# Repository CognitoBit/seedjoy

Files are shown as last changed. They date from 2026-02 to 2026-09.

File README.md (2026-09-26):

# SeedJoy

Game-controller firmware for the **Seeed Studio XIAO nRF52840**, with a zero-install web
configurator. The board shows up as a standard HID **joystick** over **USB** or **Bluetooth LE**,
with up to **56 buttons** (74HC165 shift registers) and **4 analog axes**.

> **Board:** Seeed Studio XIAO nRF52840, the *non-Sense* board, using the **"Seeed nRF52 Boards"**
> Arduino core (FQBN `Seeeduino:nrf52:xiaonRF52840`). The mbed-based Seeed core and the Sense
> board definition are not supported by this build.

---

## Features

- **56 buttons** from up to 7 daisy-chained 74HC165s on 3 pins (D6/D7/D8), debounced
- **4 analog axes** (A0–A3, 12-bit) with calibration, deadzone, expo curve, smoothing, invert
- **USB HID or BLE HID**, chosen at boot by pin D9
- **Web configurator** (Chrome/Edge): connect over **Web Serial** (USB cable, either mode) or
  **WebBluetooth** (BLE mode), read and write the full config, calibrate axes, and watch live
  button states
- **Persistent config** in on-chip flash (LittleFS, CRC32-checked)
- **Ghost-input protection**: HID input is held off for 60 s after each BLE connection
- **Battery level** reported through the BLE Battery Service (LiPo on the XIAO's BAT pads)
- Force feedback (USB PID) exists as an experimental, **off-by-default** build option, see
  [docs/ffb-plan.md](docs/ffb-plan.md)

---

## Hardware

### Parts

| Part | Qty | Notes |
|---|-----|---|
| Seeed Studio XIAO nRF52840 | 1 | Non-Sense |
| 74HC165 shift register | 1–7 | 8 buttons each |
| 10 kΩ resistor | 1 per button | Pull-up on each 74HC165 input |
| Buttons / switches | up to 56 | Input → GND |
| 10 kΩ linear potentiometer | 0–4 | Optional axes |
| Switch or jumper on D9 | 1 | Only to boot into BLE mode |
| 3.7 V single-cell LiPo | 0–1 | Optional, for wireless use |

**Everything runs at 3.3 V.** Power the 74HC165s, pull-ups and pots from the XIAO's **3V3** pin.
XIAO pins are not 5 V tolerant.

### Pin map

| XIAO pin | Port | Function |
|---|---|---|
| A0–A3 (D0–D3) | P0.02, P0.03, P0.28, P0.29 | Axes 0–3 (X, Y, Z, Rz), **disabled by default** |
| D4, D5, D10 | P0.04, P0.05, P1.15 | Optional direct GPIO buttons, disabled by default |
| **D6** | P1.11 | 74HC165 **data**: QH (pin 9) of the chip nearest the XIAO |
| **D7** | P1.12 | 74HC165 **clock**: CLK (pin 2) of every chip |
| **D8** | P1.13 | 74HC165 **load**: SH/LD (pin 1) of every chip |
| **D9** | P1.14 | **Mode select**: open = USB, GND at boot = BLE |
| RGB LED | P0.26 red, P0.06 blue | Red: booting / error blinks. Blue: USB mounted, or BLE connected |
| BAT+/BAT− pads | n/a | LiPo (underside) |

### Shift-register wiring (74HC165)

```
            far end                                          nearest XIAO
 3V3 → SER[Chip 1]QH → SER[Chip 2]QH → … → SER[Chip 7]QH ──────────► D6
        buttons 1–8    buttons 9–16          buttons 49–56

 D7 → CLK (pin 2) of every chip        D8 → SH/LD (pin 1) of every chip
 3V3 → VCC (16) of every chip           GND → GND (8) and CLK INH (15) of every chip
```

- Chain with **QH (pin 9) → next chip's SER (pin 10)**. Do not use /QH (pin 7); it's inverted.
- The far-end chip's SER goes to **3V3** (so unused chain positions read as released). Buttons
  1–8 are on that chip: input A = button 1, input H = button 8.
- Each input gets a **10 kΩ pull-up to 3V3**, and the switch goes from the input to **GND**.
  Released reads HIGH, pressed reads LOW. The default *Invert Logic = on* reports pressed as 1.
- Fewer than 7 chips is fine. Set **Number of chips** in the configurator to match what's fitted,
  because numbering always starts at the far-end chip.

Full wiring guide with the 74HC165 pinout: [docs/hardware.md](docs/hardware.md).

**Test board:** a ready-to-fab KiCad board that exercises everything (74HC165 + 8 buttons, chain
header, DIP switches, on-board thumbstick, external analog header) is in [pcb/](pcb/). See
[pcb/README.md](pcb/README.md) for the bring-up checklist and [pcb/BOM.md](pcb/BOM.md) for
India-sourced parts.

---

## Build and flash

### 1. Install the board support package

Arduino IDE 2.x or [arduino-cli](https://arduino.github.io/arduino-cli/latest/installation/).
Add this board-manager URL:

```
https://files.seeedstudio.com/arduino/package_seeeduino_boards_index.json
```

Install **Seeed nRF52 Boards** (tested with **1.1.10**). Do *not* install the "mbed-enabled"
package. No extra libraries are needed: TinyUSB, Bluefruit and LittleFS ship with the core.
Don't install a separate "Adafruit TinyUSB" from Library Manager, since it can shadow the
core's copy.

```bash
arduino-cli config add board_manager.additional_urls \
  https://files.seeedstudio.com/arduino/package_seeeduino_boards_index.json
arduino-cli core update-index
arduino-cli core install Seeeduino:nrf52
```

### 2. Compile

```bash
cd firmware/seedjoy
./compile.sh
```

This produces `build/seedjoy.uf2` (drag-and-drop image), `build/seedjoy.ino.zip` (serial DFU
package) and `build/seedjoy.ino.hex`. `compile.sh` uses `arduino-cli` from your `PATH` (or
`~/bin/arduino-cli`).

In the Arduino IDE: open `firmware/seedjoy/seedjoy.ino`, select **Tools → Board → Seeed nRF52
Boards → Seeed XIAO nRF52840** (not "Sense"), then Upload.

### 3. Flash

**Option A: UF2 drag-and-drop (simplest)**

1. Connect the XIAO by USB-C (use a data cable).
2. **Double-tap the RESET button.** A USB drive appears (the UF2 bootloader).
3. Copy `build/seedjoy.uf2` onto that drive. The board reboots into SeedJoy.

**Option B: serial upload**

```bash
./upload.sh              # finds /dev/cu.usbmodem* (macOS) or /dev/ttyACM* (Linux)
PORT=/dev/cu.usbmodem1101 ./upload.sh   # or pick the port yourself
```

Or in the IDE, press Upload. If the port isn't found, double-tap RESET and retry.

### Apple Silicon Macs without Rosetta

Seeed's core 1.1.10 ships **x86_64-only** `arm-none-eabi-gcc` 9-2019q4 and `adafruit-nrfutil`,
and Arduino's `ctags` is x86_64-only too. Without Rosetta, compiling fails with
`bad CPU type in executable`. Either install Rosetta (`softwareupdate --install-rosetta`), or
point the scripts at native tools:

```bash
# 1. Native ARM toolchain (Arm GNU Toolchain, darwin-arm64 tarball, e.g. 13.3.rel1)
#    https://developer.arm.com/downloads/-/arm-gnu-toolchain-downloads
# 2. adafruit-nrfutil from PyPI
python3 -m venv ~/.venvs/nrfutil && ~/.venvs/nrfutil/bin/pip install adafruit-nrfutil
# 3. Arduino's ctags fork, built natively
git clone --depth 1 --branch 5.8-arduino11 https://github.com/arduino/ctags.git
cd ctags && grep -rl __unused__ . | grep -E '\.(c|h)$' | xargs sed -i '' 's/__unused__/CTAGS_UNUSED/g'
./configure && make && cd ..

# then:
ARM_GCC_BIN=/path/to/arm-gnu-toolchain-13.3.rel1-darwin-arm64-arm-none-eabi/bin \
NRFUTIL=~/.venvs/nrfutil/bin/adafruit-nrfutil \
CTAGS_DIR=/path/to/ctags \
./compile.sh

NRFUTIL=~/.venvs/nrfutil/bin/adafruit-nrfutil ./upload.sh   # or just use the UF2 drive
```

This is how the current tree was build-verified: gcc 13.3.rel1, 148 KB flash (18 %), 20.6 KB RAM
(8 %). The "`_close is not implemented`"-style linker warnings from newer newlib are harmless.

---

## First boot and mode selection

D9 is sampled **once at boot** (internal pull-up):

| D9 at reset | Mode | What the host sees |
|---|---|---|
| Nothing connected | **USB** | USB joystick "SeedJoy" + a serial port (VID `0x239A`, PID `0x80F4`) |
| Tied to GND | **BLE** | BLE HID joystick advertising as "SeedJoy" (plus the serial port if USB is plugged in) |

To change mode, change D9 and press RESET. The `mode` field in the saved config is currently
informational only, and D9 always decides.

In USB mode the serial port drops once and reappears about a second after boot. That's expected:
the firmware forces the host to re-enumerate so the joystick interface appears.

Boot log (Serial Monitor, 115200 baud) prints the selected mode, enabled axes and the
shift-register setup.

### Default configuration

| Setting | Default |
|---|---|
| Shift registers | **enabled**, 7 chips, D6/D7/D8, Invert Logic **on** |
| Axes 0–3 | **disabled** (enable only the ones you've wired) |
| Direct GPIO buttons | disabled |
| Device name | `SeedJoy` |

With a full 7-chip chain, a board wired as above works with no configuration at all: SR buttons
appear as HID buttons 1–56. With fewer chips, the fitted chips first show up at the top of the
range (one chip on D6 = buttons 49–56) until you set *Number of chips* in the configurator. Nothing
reads as stuck pressed, as long as the far-end SER is tied to 3V3.

> **Upgrading from an older build?** A config already saved on the board keeps its old values.
> In particular the old default was *Invert Logic = off*, which makes every idle button read as
> pressed with pull-up wiring. Open the configurator, **Read from Device**, tick **Invert Logic**,
> and **Write to Device**.

### Testing it

- **Windows:** `joy.cpl` (Game Controllers), select SeedJoy, then Properties
- **Linux:** `jstest /dev/input/js0`
- **Any OS:** https://hardwaretester.com/gamepad in Chrome

`joy.cpl` and browser gamepad testers display **only the first 32 buttons**. The configurator's
Button Mapping tab shows all 64. Games and SDL/DirectInput apps read the full report.

### BLE mode and the 60-second window

Every time a BLE central connects (your PC *or* the web configurator), the firmware holds off
HID input for **60 seconds** so floating or unconfigured inputs can't spam the host while you
configure. The blue LED lights while connected.

- After pairing with your PC, expect **no input for the first minute** of each connection.
- Send `H` over the serial port to enable HID immediately, or `C` to restart the window.
- Press and hold a button on D9 (to GND) during the window to keep it open. A switch left
  closed since boot is ignored for this, so a permanent BLE jumper won't block HID.

Pair from the OS Bluetooth settings as you would any controller. If pairing gets stuck, remove
"SeedJoy" from the OS device list and reset the board.

---

## Web configurator

### Open it

WebBluetooth and Web Serial need a secure context. `http://localhost` counts as one:

```bash
cd configurator
python3 -m http.server 8000
# open http://localhost:8000 in Chrome or Edge (Firefox/Safari have neither API)
```

### Connect

Pick **🔌 USB Serial** or **📡 Bluetooth** at the top, then **Connect Device**.

| Mode | Transport | Works when the firmware is in |
|---|---|---|
| USB Serial (Web Serial, 115200 baud) | USB cable | USB mode **or** BLE mode (with cable plugged in) |
| Bluetooth (WebBluetooth) | Wireless GATT | BLE mode only |

The Bluetooth picker filters on names starting with `SeedJoy`. If you rename the device, keep
that prefix.

### Workflow

1. **Read from Device** loads the board's current config into the UI. Always do this first.
2. **Pin Config** tab: shift registers (enable, chip count, pins, Invert Logic), axis and GPIO
   button enables.
3. **Axis Calibration** tab: live readout, set min/center/max, deadzone, curve, smoothing.
4. **Button Mapping** tab: 56 indicators light up live as you press buttons. Over serial the
   firmware streams states at 20 Hz; over BLE they arrive as GATT notifications.
5. **Write to Device** saves to flash. Shift-register and axis changes apply immediately, no
   reboot needed.

Pin values in the configurator and in the JSON protocol are **Arduino pin numbers**
(D0–D10 = 0–10); see [docs/protocol.md](docs/protocol.md#pin-numbers).

> ⚠️ Enable only axes and buttons that are physically wired. A floating pin reads noise and
> produces phantom input.

---

## Serial protocol

115200 baud, newline-terminated text commands. Available in both USB and BLE mode.

| Command | Response | Purpose |
|---|---|---|
| `ping` | `{"type":"pong"}` | Connection check |
| `read_config` | `{"type":"config","data":{…}}` | Full config as JSON |
| `write_config:{JSON}` | `{"type":"status","success":true\|false,"message":"…"}` | Apply and save config |
| `stream_buttons` | `{"type":"buttons","data":{"states":[b0,…,b7]}}` at 20 Hz | Start live button stream (8 bytes = 64 bits) |
| `stop_stream` | `{"type":"status",…}` | Stop the button stream |
| `stream_axes` | `{"type":"axes","data":{"raw":[4],"processed":[4]}}` at 20 Hz | Live axis values (the calibration tab uses this over USB) |
| `stop_axes` | `{"type":"status",…}` | Stop the axis stream |
| `C` | text | BLE mode: (re)enter the config window, HID off |
| `H` | text | BLE mode: enable HID now |
| `?` | text | Help |

The BLE GATT config service and message formats are described in [docs/protocol.md](docs/protocol.md).

---

## HID report

One 16-byte input report. Usage page Generic Desktop, usage **Joystick**. Over USB it has no
report ID; over BLE it's Report ID 1.

```
Bytes 0–7    Axes X, Y, Z, Rz   int16 little-endian, −32767 … 32767
Bytes 8–15   Buttons 1–64       1 bit each (SR-only mode uses buttons 1–56)
```

Button bit *n* is HID button *n+1*. In SR-only mode, SR input *n* maps to bit *n*. If any direct
GPIO button is enabled, SR buttons move up by 16 (the 16 GPIO slots come first), so a 7-chip
chain's last 8 buttons no longer fit in the 64-bit report. For 56 buttons, use SR only.

---

## Troubleshooting

**Every button shows as pressed.** Invert Logic is off (a config saved by an older build). Read →
tick *Invert Logic* → Write.

**Buttons shifted / wrong numbers.** The configured chip count doesn't match the chips fitted, or
the chain is wired through /QH (pin 7) instead of QH (pin 9).

**No shift-register buttons at all.** Check D6/D7/D8 and 3V3/GND to every chip, CLK INH (pin 15)
to GND, and SR *enabled* in the config. The boot log prints the SR settings. Configs written by
older configurator builds stored invalid pin numbers (e.g. 43/44/45 for D6/D7/D8). The firmware
now repairs these at boot and logs `Repaired invalid pin numbers in stored config`.

**USB mode: no joystick, only a serial port.** Use a data cable, and check the boot log says
`USB HID initialized successfully`. On Windows, look in `joy.cpl`, not only Device Manager.

**BLE mode: connected but no input.** Wait out the 60 s window, or send `H` over serial.

**Can't find the device in the Bluetooth picker.** Check D9 was on GND at reset (the boot log
says `Selected mode: BLE`), and that the name still starts with `SeedJoy`.

**Axes drift or jitter.** Calibrate, raise the deadzone or smoothing, add 100 nF from wiper to GND.

**Config lost after reboot.** After a write the log should say `Config saved to Flash`; on the next boot, `Config loaded from Flash`. Anything else (`CRC mismatch`, `size mismatch`) means the stored config was rejected and defaults were used.

**Compile fails with `bad CPU type in executable`.** See
[Apple Silicon Macs without Rosetta](#apple-silicon-macs-without-rosetta).

More: [docs/troubleshooting.md](docs/troubleshooting.md).

---

## Project layout

```
firmware/seedjoy/
├── seedjoy.ino          setup/loop, D9 mode select, BLE config window, serial commands
├── config.h             DeviceConfig struct, default pins
├── axes.*               ADC read, calibration, deadzone, curves, smoothing
├── buttons.*            GPIO + shift-register buttons, debounce, 64-bit state
├── shift_registers.*    74HC165 bit-bang reader
├── usb_hid.*            TinyUSB joystick (16-byte report)
├── ble_hid.*            Bluefruit BLE HID joystick + battery service
├── ble_config.*         GATT config / monitor / calibration service
├── storage.*            LittleFS config persistence, CRC32
├── ffb_*                Experimental force feedback (ENABLE_FFB=0 by default)
├── compile.sh / upload.sh
firmware/tests/          Host-side unit tests for the FFB engine (bash run_tests.sh)
configurator/            Static web app: index.html, app.js, serial.js, ble.js, config.js, …
docs/                    hardware.md, protocol.md, troubleshooting.md, getting-started.md, FFB docs
```

---

## Status and known limitations

- The current tree **compiles** for `Seeeduino:nrf52:xiaonRF52840` (core 1.1.10) and the host
  unit tests pass. The fixes in this revision (USB re-enumeration, LED polarity, D9 handling,
  configurator pin numbering, SR polarity default, stored-pin repair) have **not yet been verified on a physical
  board**.
- BLE config characteristics are unauthenticated (anyone in range can write config). See
  [docs/audit.md](docs/audit.md) H2.
- `mode` in the config is ignored (D9 decides), and `autoSleep` isn't implemented yet.
- Mixing GPIO buttons with a full 7-chip chain drops the last 8 SR buttons (see HID report).

## Roadmap

- [ ] Configuration import/export as a JSON file
- [ ] Rotary encoders
- [ ] 8 axes via external ADC (ADS1115)
- [ ] Button matrices
- [ ] OTA firmware update via BLE DFU

## License

MIT, see [LICENSE](LICENSE).

## Credits

Inspired by [FreeJoy](https://github.com/FreeJoy-Team/FreeJoy) by Alexandr Yaroshenko.

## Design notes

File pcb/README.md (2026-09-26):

# SeedJoy Test Board rev A: bring-up checklist

Board: `seedjoy_testboard.kicad_pro` (KiCad 10). Fab files: `seedjoy_testboard_gerbers.zip`.
Parts: [BOM.md](BOM.md), with jumper settings.

## Before ordering the PCB

- [ ] Buy the KY-023 / PS2 joystick module first. Desolder the stick and measure it: the 3 pins of
      each pot are **2.5 mm apart**, and the two pot rows are **8.73 mm from the stick centre**
      (Alps RKJXV1224005 pattern). If your clone differs, stop and report it before ordering.
- [ ] **1:1 paper-fit test** (catches a mirrored pattern and body pegs that calipers miss):
      in KiCad, File → Print F.Cu + Edge.Cuts at **100 % scale** and check the board width
      (130 mm) with a ruler. Push the desoldered stick's legs through the printed pads (from the
      printed side, stick on top). It must sit **flat**: no plastic pegs hitting the paper, and
      the X-pot row on top, the Y-pot column on the right, the switch legs at the bottom. The legs
      should protrude ≥ 2.4 mm below the body to solder through a 1.6 mm board.
      Repeat for the DIP switch, one tactile switch, RN1 and the XIAO socket pitch.

## Before powering up (bare board, multimeter)

- [ ] **3V3 to GND is not a short**: > 1 kΩ on the J2 3V3 pin vs GND.
- [ ] No XIAO fitted yet. Check continuity **J2 pin 3 (3V3) → U1 socket pin 16** and
      **J2 pin 2 (GND) → U1 socket pin 8**.

## Assembly order

1. IC socket (notch towards the XIAO side of the silkscreen), RN1 (dot = pin 1 = square pad), R1, C1.
2. DIP switch (switch 1 next to the "1 D4" label), 8 tactile switches.
3. Female headers: J1/J2 (XIAO), J3 (external analog). Male headers: J4, J5, J6, J7, J8, J9.
4. Thumbstick U2 last. Insert the **74HC165** into its socket, notch matching.
5. Plug in the XIAO **with USB-C towards the top edge** ("USB up" silkscreen).

## First power-up (no jumpers fitted, all DIP switches OFF)

1. Flash firmware: double-tap RESET → `XIAO-BOOT` drive → copy `firmware/seedjoy/build/seedjoy.uf2`.
2. After about 1 s the **blue LED is on** and the red LED is off (USB HID mounted). A red LED
   blinking 5× means USB HID failed.
3. The OS lists a game controller named **SeedJoy** (`joy.cpl` on Windows, `jstest` on Linux).
4. The serial port drops and reappears once at boot (USB re-enumeration), so a terminal usually
   misses the boot log. Open it afterwards and send `?`: the command help confirms the firmware
   is alive.

## Configure (configurator → USB Serial → Connect → **Read from Device**)

- [ ] **Pin Config → Number of chips = 1**, Invert Logic **ticked** → **Write to Device**.
      (The firmware default is 7 chips. With 7, this board's buttons show up as HID 49–56.)
- [ ] **Button Mapping** tab: BTN1…BTN8 light up as indicators 1…8. Idle = all dark.
      Use this tab as the ground truth. **Windows `joy.cpl` and browser gamepad testers only
      show the first 32 buttons**, so at the default 7 chips (HID 49–56) the board would look dead
      there. That's another reason to set chips = 1 first.

## Analog

1. Fit **J8 on 1-2** (X from the on-board stick) and **J4 on row 1** (X → A0).
   Fit **J9 on 1-2** and **J5 on row 2** (Y → A1). *Never put J4 and J5 on the same row.*
2. Pin Config: enable **Axis 0** (pin A0) and **Axis 1** (pin A1) → Write.
3. Axis Calibration: raw ≈ 2048 at rest. PS2-style sticks usually **don't reach 0 / 4095** at
   the ends (often ~300–3800). That's normal, and the calibration exists for it:
   run min/center/max → Write.
4. External sensor: move J8 (or J9) to **2-3**, plug the sensor into **J3** (GND, 3V3, X, Y, SW).
   **3.3 V only.** Use a 3.3 V-capable hall sensor (e.g. SS49E / DRV5055A1 at 3.3 V).
5. **J6 on** means the stick push button (on-board or J3 SW) acts as BTN8.

## GPIO buttons and mode (DIP switch SW9)

- [ ] Enable GPIO buttons 0–2 (pins D4, D5, D10) in the configurator → Write. DIP 1–3 ON = pressed.
      **While any GPIO button is enabled, the shift-register buttons move to HID 17+.**
- [ ] **DIP 4 ON + reset** boots BLE mode (`Selected mode: BLE`). Pair "SeedJoy" from the OS.
      Input starts **60 s after each connection** (send `H` over serial to skip).
      DIP 4 back OFF + reset returns to USB mode.

## Chaining your own 74HC165 board (J7)

J7 = 3V3, GND, CLK (D7), LOAD (D8), SER-in. Your chain's last QH → J7 pin 5.
Your N chips become HID 1…8N and this board's buttons follow. Set Number of chips = N + 1.

## Known cosmetic warnings in KiCad

The DRC shows `lib_footprint_mismatch` (library metadata) and 3 "field differs" parity notes.
They don't affect fabrication. Tools → Update Footprints from Library / Update PCB from
Schematic clears them.

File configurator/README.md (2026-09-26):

# SeedJoy Web Configurator

A web-based configuration tool for the SeedJoy game controller using WebBluetooth API.

## Features

- **Zero-install:** Runs entirely in the browser
- **WebBluetooth:** Direct BLE communication with device
- **Visual pin configuration:** Interactive pinout diagram
- **Live axis calibration:** Real-time axis preview and calibration wizard
- **Button mapping:** Remap physical buttons to logical numbers
- **Advanced settings:** USB/BLE parameters, power management
- **Import/Export:** Save and load configuration profiles

## Requirements

### Browser
- Chrome 56+ (recommended)
- Edge 79+
- Opera 43+
- **Note:** WebBluetooth requires HTTPS or localhost

### Operating System
- **Windows 10+** (WebBluetooth support requires Windows 10 version 1706+)
- **macOS 10.12+**
- **Linux** (with BlueZ 5.41+)
- **Android 6.0+** (Chrome for Android)

**Not supported:** iOS (Safari doesn't support WebBluetooth)

## Running Locally

### Option 1: Python HTTP Server (Easiest)

```bash
cd configurator
python3 -m http.server 8000
```

Open browser to: `http://localhost:8000`

### Option 2: Node.js HTTP Server

```bash
cd configurator
npx http-server -p 8000
```

Open browser to: `http://localhost:8000`

### Option 3: VS Code Live Server

1. Install "Live Server" extension in VS Code
2. Right-click `index.html`
3. Select "Open with Live Server"

## Deploying to GitHub Pages

1. Fork/clone the repository
2. Enable GitHub Pages in repository settings
3. Set source to `main` branch, `/configurator` folder (or root if configurator is at root)
4. Access at: `https://yourusername.github.io/seedjoy/`

**Important:** GitHub Pages uses HTTPS by default, which is required for WebBluetooth!

## Usage

### 1. Connect to Device

1. Ensure your SeedJoy is powered on and in BLE mode
2. Click **Connect Device** button
3. Select **SeedJoy** (the configured device name) from the device list
4. Allow pairing if prompted

### 2. Read Configuration

1. Once connected, click **Read from Device**
2. Current configuration will be loaded from the device
3. UI will update to show current settings

### 3. Configure

Navigate through tabs to configure:

**Pin Configuration:**
- Assign axes to analog pins (A0-A3)
- Assign buttons to digital pins
- Validate pin assignments

**Axis Calibration:**
- Select axis to calibrate
- Move axis to min/center/max positions
- Click calibration buttons
- Adjust deadzone, curves, smoothing

**Button Mapping:**
- Remap physical buttons to logical numbers
- Invert button logic if needed
- Test buttons in real-time

**Advanced Settings:**
- Change device name
- Set operation mode (USB/BLE/Auto)
- Adjust USB poll rate
- Configure BLE connection interval and TX power
- Set up power management

### 4. Write to Device

1. After making changes, click **Write to Device**
2. Confirm the operation
3. Configuration will be saved to device Flash memory
4. Device will automatically apply new settings

### 5. Export/Import Configurations

**Export:**
- Click **Export Config**
- JSON file will download with timestamp
- Save for backup or sharing

**Import:**
- Click **Import Config**
- Select previously exported JSON file
- Configuration will load into UI
- Click **Write to Device** to apply

## Troubleshooting

### "Bluetooth not available"
- Check if WebBluetooth is enabled in browser flags (chrome://flags)
- Ensure Bluetooth is turned on in OS settings
- Try Chrome/Edge/Opera (WebBluetooth support required)

### "No device found"
- Ensure SeedJoy is powered on and in BLE mode
- Check the mode select: D9 must be connected to GND at boot for BLE mode
- Move closer to device (within 10m)
- Reset device and try again

### "Failed to connect"
- Unpair device in OS Bluetooth settings
- Restart browser
- Reset SeedJoy device
- Clear browser cache

### "Can't read/write configuration"
- Ensure device is connected (green indicator)
- Check firmware supports config service
- Try reconnecting
- Check serial monitor for errors

### "Configuration invalid"
- Imported config must match current firmware version
- Check JSON structure is correct
- Try resetting to defaults first
- Verify pin assignments don't conflict

### "Changes not saving"
- Must click "Write to Device" to save to Flash
- Check device connection is stable
- Verify no errors in browser console (F12)
- Try reading config again to verify

### HTTPS Required Error

WebBluetooth requires HTTPS or localhost. If you see this error:

**For local development:**
- Use `localhost` instead of `127.0.0.1`
- Or use Python/Node server (see "Running Locally")

**For production:**
- Deploy to GitHub Pages (free HTTPS)
- Use Netlify/Vercel (free HTTPS)
- Set up SSL certificate on your server

## File Structure

```
configurator/
├── index.html          # Main UI
├── styles.css          # Styling
├── app.js              # Main application logic
├── ble.js              # WebBluetooth communication
├── config.js           # Configuration management
├── calibration.js      # Axis calibration
└── assets/             # Images, icons (optional)
```

## Development

### Modifying the UI

Edit `index.html` and `styles.css` to customize appearance.

### Adding Features

1. **New configuration field:**
   - Add to `SeedJoyConfig.getDefaultConfig()` in `config.js`
   - Add UI element in `index.html`
   - Add event handler in `app.js`

2. **New calibration feature:**
   - Extend `CalibrationManager` in `calibration.js`
   - Add UI controls in axis calibration tab

3. **New BLE characteristic:**
   - Add UUID in `ble.js`
   - Implement read/write methods
   - Update protocol documentation

### Testing

Test with mock device (when not connected):
- Axis preview uses simulated values
- Button test can be triggered via keyboard (future enhancement)
- Configuration changes work offline, just can't sync to device

### Browser Console

Open Developer Tools (F12) to see:
- Connection status logs
- Configuration read/write operations
- Error messages
- BLE characteristic data

## API Reference

### SeedJoyBLE Class

```javascript
const ble = new SeedJoyBLE();

// Connect to device
await ble.connect();

// Check connection
if (ble.isConnected()) { ... }

// Read config
const config = await ble.readConfig();

// Write config
await ble.writeConfig(config);

// Read status
const status = await ble.readStatus();

// Disconnect
await ble.disconnect();

// Callbacks
ble.onConnectionChange = (connected) => { ... };
ble.onBatteryChange = (level) => { ... };
```

### SeedJoyConfig Class

```javascript
const config = new SeedJoyConfig();

// Get default config
const defaultConfig = config.getDefaultConfig();

// Update axis
config.updateAxis(0, { deadzone: 10 });

// Update button
config.updateButton(0, { logicalNumber: 5 });

// Update device settings
config.updateDeviceSettings({ deviceName: "MyStick" });

// Export to file
config.exportToFile();

// Import from file
await config.importFromFile(file);

// Reset to defaults
config.resetToDefaults();
```

### CalibrationManager Class

```javascript
const calibration = new CalibrationManager(ble, config);

// Start live monitoring
calibration.startMonitoring();

// Set axis for calibration
calibration.setCurrentAxis(0);

// Calibrate points
await calibration.calibrateMin();
await calibration.calibrateCenter();
await calibration.calibrateMax();

// Stop monitoring
calibration.stopMonitoring();
```

## Contributing

Contributions welcome! Areas for improvement:
- Better mobile support
- Dark mode toggle
- SVG pinout diagram
- Custom curve editor (canvas-based)
- Button macro system
- Telemetry/analytics view
- OTA firmware update UI

## License

MIT License - see root LICENSE file

## See Also

- [Main README](../README.md)
- [Getting Started Guide](../docs/getting-started.md)
- [Configuration Protocol](../docs/protocol.md)
- [Hardware Wiring](../docs/hardware.md)

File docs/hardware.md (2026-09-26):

# Hardware Wiring Guide

How to wire SeedJoy on a **Seeed Studio XIAO nRF52840** (the non-Sense board; the Sense
variant uses a different Arduino board definition and is not what the build targets).

Everything on the XIAO is **3.3 V logic. No pin is 5 V tolerant.** Power every external
chip and potentiometer from the XIAO's **3V3** pin, never from 5V.

## Components

| Part | Qty | Notes |
|---|-----|---|
| Seeed Studio XIAO nRF52840 | 1 | Non-Sense |
| 74HC165 (8-bit parallel-in / serial-out) | 1–7 | 8 buttons per chip, 56 max |
| 10 kΩ resistor | 1 per button | Pull-up on each 74HC165 input |
| Push buttons / switches | up to 56 | Wired input → GND |
| 10 kΩ linear potentiometer | 0–4 | Analog axes on A0–A3 |
| Switch or jumper on D9 | 1 | Only needed to boot into BLE mode |
| 100 nF ceramic capacitor | optional | One per 74HC165 (VCC–GND), one per pot wiper (to GND) |
| 3.7 V LiPo | optional | Wireless (BLE) use |

## XIAO nRF52840 pins used by SeedJoy

Physical layout, board seen from the top with the USB-C connector pointing up:

```
            USB-C
       ┌─────────────┐
  D0/A0│●           ●│5V
  D1/A1│●           ●│GND
  D2/A2│●           ●│3V3
  D3/A3│●           ●│D10
     D4│●           ●│D9
     D5│●           ●│D8
     D6│●           ●│D7
       └─────────────┘
```

| XIAO pin | nRF52840 port | SeedJoy function (default) |
|---|---|---|
| A0 / D0  | P0.02 | Axis 0 (X), disabled until enabled in the configurator |
| A1 / D1  | P0.03 | Axis 1 (Y), disabled until enabled |
| A2 / D2  | P0.28 | Axis 2 (Z), disabled until enabled |
| A3 / D3  | P0.29 | Axis 3 (Rz), disabled until enabled |
| D4 | P0.04 | Optional direct GPIO button (disabled) |
| D5 | P0.05 | Optional direct GPIO button (disabled) |
| D6 | P1.11 | **74HC165 serial data in** (QH, pin 9, of the chip nearest the XIAO) |
| D7 | P1.12 | **74HC165 clock** (CLK, pin 2, all chips) |
| D8 | P1.13 | **74HC165 load** (SH/LD, pin 1, all chips) |
| D9 | P1.14 | **Mode select** (see below) |
| D10 | P1.15 | Optional direct GPIO button (disabled) |
| 3V3 | n/a | Power for 74HC165s, pull-ups, pots |
| GND | n/a | Common ground |
| On-board RGB LED | P0.26 red / P0.06 blue | Red = booting / error blink, blue = USB mounted or BLE connected |
| BAT+ / BAT− pads (underside) | n/a | LiPo |

The firmware uses Arduino pin numbers (`D6` = 6, `A0` = 0, and so on). The configurator's pin
drop-downs use the same numbers.

## Mode select (D9)

D9 is read **once at boot** with the internal pull-up enabled:

| D9 at power-up / reset | Mode |
|---|---|
| Not connected (floating → pulled HIGH) | **USB** HID |
| Connected to GND | **BLE** HID |

```
XIAO D9 ────o/ o──── GND        (switch closed at boot = BLE)
```

A toggle switch, a jumper or a momentary button all work. In BLE mode, holding D9 LOW
*again after it has been released* keeps the 60-second configuration window open (see
README). A switch left permanently closed does **not** block HID.

The `mode` value stored in the device config is currently informational only. D9 decides
the mode on every boot.

## Shift registers (74HC165), up to 56 buttons

### 74HC165 pinout (DIP-16 / SOIC-16)

```
              ┌───∪───┐
   SH/LD  1 ──┤       ├── 16  VCC  (3V3 only!)
     CLK  2 ──┤       ├── 15  CLK INH  → GND
       E  3 ──┤       ├── 14  D
       F  4 ──┤       ├── 13  C
       G  5 ──┤       ├── 12  B
       H  6 ──┤       ├── 11  A
     /QH  7 ──┤       ├── 10  SER
     GND  8 ──┤       ├──  9  QH
              └───────┘
```

Inputs A–H are sometimes labelled D0–D7 in datasheets. Leave **/QH (pin 7) unconnected**; it's
the *inverted* output and must not be used for chaining.

### Daisy chain

Every chip shares SH/LD (→ D8) and CLK (→ D7). Data flows from the far end of the chain toward
the XIAO: each chip's **QH (pin 9)** goes to the next chip's **SER (pin 10)**, and the QH of the
chip nearest the XIAO goes to **D6**. Tie the SER of the far-end chip to **3V3**. With the default inverted logic, a HIGH reads as
"released", so any chain positions beyond the fitted chips stay released.

```
            far end                                          nearest XIAO
 3V3 → SER[Chip 1]QH → SER[Chip 2]QH → … → SER[Chip 7]QH ──────────► D6
        buttons 1–8    buttons 9–16          buttons 49–56

 D7 ──► CLK   of every chip        D8 ──► SH/LD of every chip
 GND ─► CLK INH and GND of every chip; 3V3 ─► VCC of every chip
```

With fewer chips, the numbering still starts at the far end: with 3 chips, Chip 1 (far end,
SER → 3V3) is buttons 1–8 and the chip on D6 is buttons 17–24. **Set "Number of chips" in the
configurator to the number of chips actually fitted.** A mismatch shifts every button.

### Button inputs

The 74HC165 has no internal pull-ups. Give every input (A–H) a 10 kΩ pull-up to 3V3 and wire
the switch from that input to GND:

```
3V3 ── 10kΩ ──┬── 74HC165 input (A…H)
              └── switch ── GND
```

A released button reads HIGH and a pressed one reads LOW. The firmware default
**`inverted = true`** (configurator: *Invert Logic* checked) turns that into pressed = 1. Tie
any unused input HIGH (through its pull-up) so it reads as released.

### Button numbering

HID button numbers as shown by Windows / `jstest` / gamepad-tester (1-based):

| Chip (1 = far end) | Input A | … | Input H |
|---|---|---|---|
| 1 | 1  | … | 8  |
| 2 | 9  | … | 16 |
| 3 | 17 | … | 24 |
| 4 | 25 | … | 32 |
| 5 | 33 | … | 40 |
| 6 | 41 | … | 48 |
| 7 | 49 | … | 56 |

(Firmware/configurator indices are 0-based: HID button 1 = index 0.)

### Direct GPIO buttons (optional)

D4, D5 and D10 can take a button straight to GND (internal pull-up, no resistor). Enable them in
the configurator. **Enabling any GPIO button moves every shift-register button up by 16** (SR
button 1 becomes HID button 17), so with 7 chips the last 8 SR buttons no longer fit in the
64-button report. For 56 SR buttons, leave the GPIO buttons disabled.

## Potentiometers (analog axes)

```
3V3 ──── pot end
A0  ──── pot wiper      (A1, A2, A3 for axes 1–3)
GND ──── pot other end
```

Axes are **disabled by default** because a floating ADC pin produces random axis movement. Enable
only the axes you have wired, then calibrate them in the configurator. A 100 nF capacitor from
each wiper to GND reduces jitter.

## Battery (optional)

Solder a single-cell 3.7 V LiPo to the **BAT+ / BAT−** pads on the underside of the XIAO. The
on-board charger charges it while USB is connected. In BLE mode the firmware reads the battery
voltage every 60 s (via the on-board divider on P0.31, enabled through P0.14) and reports it
through the BLE Battery Service. The voltage-to-percent conversion is a rough linear estimate.

## Safety notes

- 3.3 V only on every pin. A 74HC165 powered from 5 V will put 5 V on D6.
- Observe LiPo polarity. Reversing it destroys the charger.
- Unconnected but enabled inputs cause phantom input. Enable only what's wired.

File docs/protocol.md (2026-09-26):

# Configuration Protocol

This document describes the configuration protocol used to communicate between the web configurator and the SeedJoy firmware.

## Overview

SeedJoy supports configuration via:
1. **BLE GATT Characteristics** (primary method for wireless config)
2. **Serial Commands** (development/debugging)
3. **USB HID Reports** (future enhancement)

## BLE Configuration Service

### Service UUID
```
CONFIG_SERVICE_UUID = e95d0001-251d-470a-a062-fa1922dfa9a8
```

### Characteristics

#### 1. Config Characteristic (Read/Write)
```
UUID: e95d0002-251d-470a-a062-fa1922dfa9a8
Properties: Read, Write
Max Size: 512 bytes (may require fragmentation)
```

**Purpose:** Transfer full device configuration

**Format:** JSON (UTF-8 encoded)

**Example Read Response:**
```json
{
  "magic": 1593968567,
  "configVersion": 1,
  "firmwareMajor": 0,
  "firmwareMinor": 1,
  "firmwarePatch": 0,
  "deviceName": "SeedJoy",
  "mode": 0,
  "usbVID": 9242,
  "usbPID": 32500,
  "usbPollRate": 1,
  "bleConnInterval": 2,
  "bleTxPower": 0,
  "axes": [
    {
      "pin": 2,
      "enabled": true,
      "inverted": false,
      "min": 0,
      "center": 2048,
      "max": 4095,
      "deadzone": 5,
      "curveType": 0,
      "expoFactor": 0.0,
      "customCurve": [0.0, 0.25, 0.5, 0.75, 1.0],
      "smoothing": 0
    },
    // ... 3 more axes
  ],
  "buttons": [
    {
      "pin": 4,
      "enabled": true,
      "logicalNumber": 0,
      "inverted": false
    },
    // ... 15 more buttons
  ],
  "autoSleep": false,
  "sleepTimeout": 600,
  "crc32": 305441816
}
```

**Write:** Send JSON configuration to update device settings. Device will validate, calculate CRC, and store in Flash.

#### 2. Status Characteristic (Read, Notify)
```
UUID: e95d0004-251d-470a-a062-fa1922dfa9a8
Properties: Read, Notify
Max Size: 256 bytes
```

**Purpose:** Query device status and real-time axis/button values

**Format:** JSON (UTF-8 encoded)

**Example Response:**
```json
{
  "mode": "USB",
  "firmwareVersion": "0.1.0",
  "connected": true,
  "batteryLevel": 87,
  "axes": [
    { "raw": 2048, "processed": 0 },
    { "raw": 1024, "processed": -16384 },
    { "raw": 3072, "processed": 16384 },
    { "raw": 2048, "processed": 0 }
  ],
  "buttons": 0b0000000000001101
}
```

**Notifications:** Subscribe to get real-time updates (useful for calibration/testing)

## Serial Commands

For debugging and development, configuration can be done via USB Serial.

### Format
```
COMMAND [ARGS]\n
```

### Commands

#### GET_CONFIG
Get full configuration as JSON
```
GET_CONFIG
```

Response:
```json
{...}
```

#### SET_CONFIG
Set configuration from JSON (paste entire JSON on one line)
```
SET_CONFIG {"magic": 1593968567, "configVersion": 1, ...}
```

Response:
```
OK
```

#### GET_STATUS
Get current status
```
GET_STATUS
```

Response:
```json
{"mode": "USB", "firmwareVersion": "0.1.0", ...}
```

#### CALIBRATE_AXIS
Calibrate axis min/center/max
```
CALIBRATE_AXIS <axis_index> <min|center|max>
```

Example:
```
CALIBRATE_AXIS 0 min    # Set axis 0 minimum to current value
CALIBRATE_AXIS 0 center # Set axis 0 center to current value
CALIBRATE_AXIS 0 max    # Set axis 0 maximum to current value
```

#### RESET_CONFIG
Reset to default configuration
```
RESET_CONFIG
```

#### REBOOT
Reboot device
```
REBOOT
```

#### SET_MODE
Change operation mode
```
SET_MODE <usb|ble|auto>
```

#### GET_AXIS
Get current axis raw value
```
GET_AXIS <index>
```

Response:
```
AXIS 0: raw=2048 processed=0
```

#### GET_BUTTONS
Get current button states
```
GET_BUTTONS
```

Response:
```
BUTTONS: 0b0000000000001101 (0x000D)
  0: 1
  1: 0
  2: 1
  3: 1
  ...
```

## Configuration Structure

### DeviceConfig

| Field | Type | Default | Description |
|---|---|---|---|
| magic | uint32 | 0x5EED70B7 | Magic number for validation |
| configVersion | uint8 | 1 | Config structure version |
| firmwareMajor | uint8 | 0 | Firmware major version |
| firmwareMinor | uint8 | 1 | Firmware minor version |
| firmwarePatch | uint8 | 0 | Firmware patch version |
| deviceName | char[32] | "SeedJoy" | BLE device name |
| mode | uint8 | 0 | 0=USB, 1=BLE, 2=AUTO |
| usbVID | uint16 | 0x239A | USB Vendor ID |
| usbPID | uint16 | 0x80F4 | USB Product ID |
| usbPollRate | uint8 | 1 | USB poll rate (ms) |
| bleConnInterval | uint16 | 2 | BLE connection interval (1.25ms units) |
| bleTxPower | int8 | 0 | BLE TX power (dBm) |
| axes | AxisConfig[4] | See below | Axis configurations |
| buttons | ButtonConfig[16] | See below | Button configurations |
| autoSleep | bool | false | Auto sleep enabled |
| sleepTimeout | uint16 | 600 | Sleep timeout (seconds) |
| crc32 | uint32 | calculated | CRC32 checksum |

### AxisConfig

| Field | Type | Default | Description |
|---|---|---|---|
| pin | uint8 | 0–3 | Arduino analog pin (0 = A0 … 3 = A3), see Pin Numbers |
| enabled | bool | false | Axis enabled (off by default; floating ADC pins cause noise) |
| inverted | bool | false | Invert axis direction |
| min | uint16 | 0 | Calibrated minimum (0-4095) |
| center | uint16 | 2048 | Calibrated center (0-4095) |
| max | uint16 | 4095 | Calibrated maximum (0-4095) |
| deadzone | uint8 | 5 | Deadzone percentage (0-50) |
| curveType | uint8 | 0 | 0=Linear, 1=Expo, 2=Custom |
| expoFactor | float | 0.0 | Exponential factor (0.0-1.0) |
| customCurve | float[5] | [0.0, 0.25, 0.5, 0.75, 1.0] | Custom curve points |
| smoothing | uint8 | 0 | Smoothing samples (0, 2, 4, 8) |

### ButtonConfig

| Field | Type | Default | Description |
|---|---|---|---|
| pin | uint8 | 4, 5, 10, 255… | Arduino pin number, see Pin Numbers |
| enabled | bool | false | Button enabled (off by default; SR-only mode) |
| logicalNumber | uint8 | index | Logical button number (0-15) |
| inverted | bool | false | Invert logic (HIGH=pressed) |

## Pin Numbers

All `pin`, `dataPin`, `clockPin` and `loadPin` values are **Arduino pin numbers** for the Seeed
XIAO nRF52840 core, i.e. the numbers the firmware passes straight to `pinMode()` /
`digitalRead()` / `analogRead()`. They are **not** nRF52840 GPIO (P0.xx / P1.xx) numbers.
`255` (`0xFF`) means "not used".

| Value | XIAO pin | nRF52840 port | Default use |
|---|---|---|---|
| 0  | A0 / D0 | P0.02 | Axis 0 |
| 1  | A1 / D1 | P0.03 | Axis 1 |
| 2  | A2 / D2 | P0.28 | Axis 2 |
| 3  | A3 / D3 | P0.29 | Axis 3 |
| 4  | D4 (SDA) | P0.04 | GPIO button (disabled) |
| 5  | D5 (SCL) | P0.05 | GPIO button (disabled) |
| 6  | D6 (TX) | P1.11 | 74HC165 data (QH) |
| 7  | D7 (RX) | P1.12 | 74HC165 clock |
| 8  | D8 (SCK) | P1.13 | 74HC165 load (SH/LD) |
| 9  | D9 (MISO) | P1.14 | Mode select, don't assign |
| 10 | D10 (MOSI) | P1.15 | GPIO button (disabled) |

Only values 0–3 are valid for axes (ADC-capable pins wired to the XIAO header).

## CRC32 Calculation

The firmware calculates CRC32 over the entire config structure excluding the `crc32` field itself.

**Algorithm:** Standard CRC32 (polynomial 0xEDB88320)

**JavaScript Implementation:**
```javascript
function calculateCRC32(config) {
    // Exclude crc32 field
    const data = JSON.stringify({...config, crc32: 0});
    const bytes = new TextEncoder().encode(data);
    
    let crc = 0xFFFFFFFF;
    for (let i = 0; i < bytes.length; i++) {
        crc ^= bytes[i];
        for (let j = 0; j < 8; j++) {
            if (crc & 1) {
                crc = (crc >>> 1) ^ 0xEDB88320;
            } else {
                crc >>>= 1;
            }
        }
    }
    return ~crc >>> 0;
}
```

## Error Handling

### Validation Errors

If config validation fails, device returns error:

**BLE:** Write fails with GATT error
**Serial:** 
```
ERROR: Invalid magic number
ERROR: Invalid config version
ERROR: CRC mismatch
ERROR: Invalid pin assignment
```

### Recovery

If config is corrupted:
1. Device boots with default configuration
2. Serial monitor shows warning: "Config validation failed"
3. Use web configurator or serial to write new config
4. Or send `RESET_CONFIG` command

## Example Workflows

### Calibrate Axis via Serial

```
# Connect to serial monitor (115200 baud)

# Check current axis 0 value
GET_AXIS 0
> AXIS 0: raw=150 processed=-32767

# Move axis to minimum position
CALIBRATE_AXIS 0 min
> OK: Axis 0 min set to 150

# Move to center
CALIBRATE_AXIS 0 center
> OK: Axis 0 center set to 2048

# Move to maximum
CALIBRATE_AXIS 0 max
> OK: Axis 0 max set to 3950

# Verify
GET_CONFIG
> {...}
```

### Update via Web Configurator

```javascript
// In configurator JavaScript

// Read config
const config = await ble.readConfig();

// Modify
config.axes[0].deadzone = 10;
config.deviceName = "MyFlightStick";

// Write back
await ble.writeConfig(config);
```

## Future Enhancements

- **Firmware Update Protocol:** OTA updates via BLE DFU
- **Profile System:** Save/load multiple configurations
- **Macro Support:** Button combinations trigger sequences
- **Telemetry:** Axis/button usage statistics
- **USB HID Config:** Configure via USB without BLE

## See Also

- [Getting Started Guide](getting-started.md)
- [Hardware Wiring](hardware.md)
- [Web Configurator Documentation](../configurator/README.md)

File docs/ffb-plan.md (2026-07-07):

# SeedJoy Force-Feedback (FFB) Plan

**Goal:** evolve SeedJoy into a force-feedback HID device that games recognize natively
(DirectInput / SDL haptics), rendering effects on real actuators.

**Ground rules established by the audit (`docs/audit.md`):**

- FFB will be implemented as a **USB HID PID** (Physical Interface Device, usage page 0x0F)
  device. That is the only path DirectInput/SDL treat as force feedback.
- **BLE stays input-only.** No mainstream host OS delivers PID over BLE HID (HOGP); commercial
  controllers do wireless rumble only via proprietary reports + custom drivers. Additionally, FFB
  motors need a mains/bench supply — battery operation and FFB are mutually exclusive in practice.
- Nothing off-the-shelf exists for nRF52840 + TinyUSB — the PID descriptor, report plumbing, and
  effect engine are custom work. The MCU itself is comfortably capable (1 kHz HID, 4× PWM
  peripherals, 256 KB RAM).

---

## Implementation status (2026-07-08)

Phases 1–3 are implemented to **production-grade code** plus a working Phase 4 motor abstraction,
gated behind `ENABLE_FFB` (default **0**). **With the gate off, the built firmware is byte-identical
to the non-FFB baseline** — re-verified after all production changes by diffing the compiled flash
image against commit `8cd31f9`. Turn it on with `-DENABLE_FFB=1` (or edit `ffb_config.h`).

The one thing that *cannot* be verified without hardware is the USB PID descriptor's acceptance by a
real host; everything host-verifiable is covered by 67 unit assertions (`firmware/tests/run_tests.sh`).

| Piece | Files | Status | How verified |
|---|---|---|---|
| Effect engine — constant, ramp, spring, damper, inertia, friction, periodic, envelope, **per-axis conditions**, **loop count**, mixing, device gain, **hard safety clamp** | `ffb_engine.*`, `ffb_types.h` | **Production, unit-tested** | `ffb_engine_test.cpp` — 31 assertions |
| PID runtime — Create→Block Load→Pool handshake, all `Set*` parsers, **per-axis conditions**, **polar direction**, Device Control/Gain, Effect Operation, Block Free, PID State (playing index) | `ffb_reports.h`, `ffb_runtime.*` | **Production, unit-tested** | `ffb_runtime_test.cpp` — 19 assertions (raw wire bytes) |
| PID report **descriptor** | `ffb_reports.cpp` | **Structurally validated, host-acceptance UNVERIFIED** | `ffb_descriptor_test.cpp` — 17 assertions: collections balance, every report's size matches its struct. Still **not** proven against a real HID stack. |
| Concurrency — engine access serialized across the `usbd` and `loop` tasks | `ffb_lock.*`, `usb_hid.cpp`, `seedjoy.ino` | **Fixed (FreeRTOS mutex)** | compiles; needs the on-hardware stress test (physical plan §7) |
| Phase 1 USB restructure — Report ID 1 joystick, OUT endpoint, GET/SET_REPORT dispatch, bumped PID | `usb_hid.*` | **Implemented, compiles** | both gate states build; **not** host-tested |
| Phase 3 driver — ~1 kHz tick, mutex-guarded engine step, USB-detach safety cutoff | `seedjoy.ino` | **Implemented, compiles** | loop-based (a hardware-timer ISR is a future refinement, not required) |
| Phase 4 motor output — driver-type-aware (PWM+DIR / dual-PWM), global duty clamp, LED viz | `ffb_motor.*` | **Abstraction ready, NO pins assigned** | no actuator wired; axis-0 force mirrored to status LED |

**Concurrency fix (resolved).** USB report callbacks run in the high-priority FreeRTOS `usbd` task
(verified: `tud_task()` loops there — `Adafruit_TinyUSB_nrf.cpp`); the force tick runs in the
low-priority `loop` task. Both touch engine state, so a single mutex (`ffb_lock`) serializes them.
A mutex — not the report queue floated earlier — is correct because the Create→Block Load handshake
is a synchronous control transfer that must be serviced in the usbd task; a queue would defer Create
and make Block Load read stale state. The loop holds the lock only across the pure-math engine step,
so priority inversion is bounded and deadlock impossible.

**The one remaining unknown is the descriptor's host acceptance** — that is what the physical test
plan exists to close. Do **not** treat "compiles + unit tests pass" as "a host drives it."

**Immediate next steps (no motor needed — see `docs/ffb-physical-tests.md`):**
1. Parse `FFB_HID_REPORT_DESCRIPTOR` with a HID decoder; enumerate on Linux, run `fftest`; watch the
   Create→Block Load handshake in `usbmon`.
2. Confirm the joystick half still enumerates (`jstest`) with the new Report ID 1.
3. Stress the concurrency fix (hammer effect uploads while the force loop runs).
4. Then Windows (`fedit`) and, separately, wire a motor (assign pins in `ffb_motor.cpp::begin`).

---

## Phase 0 — Stabilize the baseline (prerequisite)

Fix the audit blockers so FFB work builds on a device that actually works:

1. **B1** compile error in `ble_config.cpp:249` (+ use the correct `"key":` pattern for floats).
2. **B3** LittleFS append bug — `InternalFS.remove()` before save.
3. **B2** switch BLE to `BLEHidGamepad` / `BLEHidGeneric` subclass with the map set before `begin()`.
4. **H3** debounce SR buttons (they'll be trigger buttons for FFB effects).
5. **M8** remove blocking `Serial` prints from the steady-state loop (the force loop cannot
   tolerate multi-ms jitter).

**Acceptance:** clean compile via `compile.sh`; config survives ≥3 save/reboot cycles; BLE mode
enumerates as a joystick on Windows/Android; USB mode unchanged.

## Phase 1 — USB HID restructuring (report IDs + OUT endpoint)

PID forces layout changes on the existing input path:

1. Add **Report ID 1** to the joystick input report (PID needs many IDs; ID-less reports can't
   coexist). Host-visible change — note in README that games may need recalibration.
2. Construct `Adafruit_USBD_HID` with `has_out_endpoint = true`; raise
   `CFG_TUD_HID_EP_BUFSIZE` if needed (64 is fine for PID).
3. Implement real `GET_REPORT` / `SET_REPORT` callbacks (feature + output), replacing the
   `nullptr` / empty stub in `usb_hid.cpp`. Route by report ID to a dispatch table.
4. Keep BLE completely untouched by this phase (separate descriptor already, per Phase 0.3).

**Acceptance:** device still works as a plain joystick in `joy.cpl` / `jstest`; a host-side test
script can round-trip a vendor feature report.

## Phase 2 — PID descriptor + block-management handshake (no motors yet)

Implement the PID class surface so hosts *believe* the device does FFB before any hardware exists.

**Input reports**
- ID 1: joystick (from Phase 1)
- ID 2: **PID State** (paused, actuators enabled, safety switch, playing, effect block index)

**Output reports** (host → device, interrupt OUT):
- Set Effect (block index, type, duration, gain, trigger, axes/direction)
- Set Envelope, Set Condition (×2 axes), Set Periodic, Set Constant Force, Set Ramp Force
- Effect Operation (start / start solo / stop, loop count)
- PID Block Free, PID Device Control (enable/disable actuators, stop all, reset, pause, continue)
- Device Gain

**Feature reports** (control transfers):
- Create New Effect (effect type in) → **PID Block Load** (block index + status out)
- **PID Pool** (pool size, max simultaneous effects, device-managed pool = 1)

**Device side:** static effect pool (start with 16 blocks × largest-effect union — device-managed,
no host pool math), allocation state machine for Create New Effect → Block Load, and a parameter
store the engine will later read. Reference implementations to crib structure (not code) from:
Arduino-FFB-wheel (AVR), VNWheel, OpenFFBoard (STM32).

**Acceptance:**
- Linux: `fftest /dev/input/eventX` lists and uploads all effect types without error.
- SDL: `testhaptic` reports the expected capability mask.
- Windows: enumerates with the PID class driver; `fedit` (DirectX SDK) can create/start effects.
- Wireshark/usbmon shows correct Block Load handshakes. No motor output — state only.

## Phase 3 — Effect engine (1 kHz force loop)

1. **Scheduler:** fixed 1 kHz tick (hardware timer, not `millis()` polling). Input scan + HID send
   stay at their current rates; the force loop must never block on Serial/BLE/flash.
2. **Per-effect rendering:**
   - Constant: magnitude × envelope × gain
   - Ramp: linear start→end over duration
   - Periodic: sine/square/triangle/sawtooth via phase accumulator
   - Condition (spring/damper/inertia/friction): f(position, velocity) with CP offset, dead band,
     ± coefficients, saturation. Position from the existing 12-bit pot pipeline; velocity via
     filtered derivative (e.g. 3-tap backward difference + IIR).
3. **Mixing:** sum active effects → clamp → device gain → signed output per axis.
4. **Safety (non-negotiable):** watchdog on the force loop; zero output on USB suspend/detach,
   PID Device Control "stop all"/"pause", or effect timeout; global duty clamp configurable in
   `DeviceConfig`.

Start with constant + spring + damper (covers most sims), then periodic, then envelopes.

**Acceptance:** with output visualized (logic analyzer / LED PWM), `fftest` spring effect produces
position-proportional opposing output; sine effect produces the right frequency; detach kills
output within 10 ms.

## Phase 4 — Actuator hardware

Pin reality on XIAO (11 GPIOs, all currently allocated): axes D0–D3, GPIO buttons D4/D5/D10
(disabled by default in SR-only mode), SR D6–D8, mode select D9.

| Option | Pins | Fits |
|---|---|---|
| **A. Single axis, direct drive** — DRV8871 (IN1/IN2) on D4/D5, optional fault/enable on D10 | 2–3 repurposed | 1-axis FFB (joystick X or wheel), simplest |
| **B. Multi-axis via I2C** — D4/D5 are the native I2C pins → PCA9685 → discrete H-bridges (or I2C motor drivers) | 2 pins, expandable | 2+ axes; PCA9685's ~1.5 kHz PWM is audible — prefer real H-bridge drivers with the PCA9685 only as DIR/EN, or pick option A per axis |
| **C. Reclaim D9** — move mode select to a boot-time button combo (hold SR button 0) | +1 pin | Frees a pin for enable/fault sensing |

Recommendation: **Option A first** (one axis end-to-end proves the whole stack), design the engine
for N axes from day one. Drive PWM at 20–25 kHz (inaudible; nRF52840 PWM handles it on any pin).

Electrical requirements: separate motor supply sized for stall current, common ground with the
XIAO, flyback/TVS protection, and the config default `usbPID` should change (new product identity
so hosts don't cache the old non-FFB descriptor — bump `usbPID`, keep VID).

**Acceptance:** spring-centering demo on real hardware; a sim title (e.g. anything SDL2-haptic or
DirectInput-based) produces believable forces.

## Phase 5 — Integration & polish

- Expose FFB settings in `DeviceConfig` + configurator: global gain, max duty, per-effect-type
  enable, motor polarity/axis mapping (extends the existing JSON config path).
- PID State input report kept truthful (paused/enabled/playing) — some games poll it.
- Docs: wiring guide for the driver board, safety notes, supported-effects matrix.
- Regression: BLE input-only mode must remain fully functional and completely FFB-free.

---

## Risks / open questions

1. **TinyUSB feature-report handling** on nRF52 for multi-ID GET_REPORT is the least-tested corner
   — validate early in Phase 2 with a USB analyzer or usbmon before building the engine.
2. **Windows PID driver quirks:** it is strict about Block Load status codes and pool reports;
   most DIY-FFB failures are handshake bugs, not engine bugs. Budget debugging time here.
3. **Pot-based position sensing** limits fidelity (noise → damper jitter). Fine for entry-level;
   a magnetic encoder (I2C, fits option B bus) is the upgrade path for a wheel.
4. **Actuator choice drives everything mechanical** (gearing, torque, back-drivability). The plan
   above is actuator-agnostic through Phase 3, which is deliberate — hardware can be selected in
   parallel.
5. **Engine thread-safety — RESOLVED (mutex).** USB report callbacks mutate engine state from the
   high-priority `usbd` task; the force tick reads it from `loop`. Serialized with a single
   priority-inheriting FreeRTOS mutex (`ffb_lock`); the loop holds it only across the pure-math
   engine step. Correct by construction, but confirm on hardware with the concurrency stress test
   (physical plan §7) — that's the one thing a host test can't exercise.

## Suggested order of work

Phase 0 is a day-scale fix batch and worth doing immediately regardless of FFB. Phases 1–2 are
pure firmware and fully testable without any new hardware. Phase 3 is testable with an LED/scope.
Hardware spend only becomes necessary at Phase 4.

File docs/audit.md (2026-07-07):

# SeedJoy Firmware Audit

**Date:** 2026-07-04
**Scope:** Full firmware (`firmware/seedjoy/`), configurator BLE write path, docs. Suspect library
behaviors were verified against the installed core at
`~/Library/Arduino15/packages/Seeeduino/hardware/nrf52/1.1.10` (Bluefruit52Lib, Adafruit_LittleFS).
**Context:** Audit performed with the project goal of evolving SeedJoy into a **force-feedback
(FFB) capable HID device**. See `docs/ffb-plan.md` for the FFB roadmap.

**Summary:** Solid input-only controller scaffold, but as of commit `e46c91a`:
the tree **does not compile** (B1), **BLE HID never presents the joystick descriptor** (B2), and
**config persistence self-corrupts on the second save** (B3). There is currently **zero FFB
support** — no PID descriptor, no OUT endpoint, no effect engine, no actuator hardware path, and
no free pins.

---

## Fix status (2026-07-07)

Applied in the working tree (not yet committed):

| Item | Status | Notes |
|---|---|---|
| B1 | **Fixed** | `ble_config.cpp` float parser now matches `"key":` (numeric). |
| B2 | **Fixed** | BLE HID switched to `BLEHidGeneric(1,0,0)`; `Report ID (1)` added to map; `setReportMap`/`setReportLen`/`setHidInfo` moved before `begin()`; both `inputReport` sites → ID 1. |
| B3 | **Fixed** | `storage.cpp` removes the file before each write (kills append growth). |
| H1 | **Fixed** | Conn interval clamped to ≥6 (7.5 ms), return checked; default 2→6; comment corrected. |
| H3 | **Fixed** | SR buttons now debounced (per-bit, same `DEBOUNCE_MS` policy as GPIO). |
| H4 | **Fixed (calibrate)** | `readVBAT()` drives `VBAT_ENABLE` LOW, sets `AR_INTERNAL_3_0`, restores; percentage now written to `blebas_`. Divider comp = 2.96 for the XIAO 1M/510k divider — **verify against a multimeter** (board-specific, not in BSP). |
| M7 | **Fixed** | README + hardware.md pin drift corrected (D9=P1.14, SR-based button map); stale/corrupted pin sections replaced; fabricated ASCII sketch flagged as non-authoritative. |
| **H2** | **Deferred — needs your decision** | Requiring `SECMODE_ENC_NO_MITM` on the config/calibrate characteristics is a real hardening win, but it forces BLE pairing and **may break the zero-install WebBluetooth configurator** on some platforms. This cannot be verified without hardware + browsers, so it is intentionally NOT applied. Options: (a) require encryption and accept a pairing step; (b) gate config writes behind the existing 60 s physical-button window; (c) accept the risk for a hobby device. Left as-is (`SECMODE_OPEN`) pending your call. |
| M1–M6, M8 | Not addressed | Lower priority; see table below. M5/M8 are folded into the FFB plan (`docs/ffb-plan.md`). |

**Verification:** these are firmware changes that cannot be flashed here. The objective gate is a
clean compile — see the "Compile" note at the bottom of this file for its status.

---

## Blockers

### B1. Stray `\` — tree does not compile
`firmware/seedjoy/ble_config.cpp:249` (`bleExtractJsonFloat`):

```cpp
String s = "\"" + key + \":\"";   // stray '\' in program → hard compile error
```

Verified byte-for-byte in both the working tree and `HEAD`. The `build/` artifacts are stale and
predate this line.

Two bugs in one: even "fixed" to `"\":\""`, the pattern searches for `"key":"` (a *quoted* value)
and never matches numeric JSON such as `"expoFactor":0.25`. The correct pattern is `"\":"` as used
in `seedjoy.ino` (`extractJsonFloat`, ~line 608). Consequence once compiling: `expoFactor` can
never be updated over BLE.

**Fix:** `String s = "\"" + key + "\":";`

### B2. BLE HID enumerates as keyboard+mouse, not joystick
`firmware/seedjoy/ble_hid.cpp:77-81` calls `blehid_.begin()` **before** `setReportMap()` /
`setHidInfo()`. Verified in Bluefruit52Lib source:

- `BLEHidAdafruit::begin()` installs the stock **keyboard/consumer/mouse** report map and creates
  the GATT Report Map + input-report characteristics (report IDs 1/2/3, fixed lengths 8/2/5 bytes)
  inside `begin()`.
- `setReportMap()` after `begin()` only stores a pointer that is never read again — the Report Map
  characteristic already holds the Adafruit default.
- `inputReport(0, &report_, 16)` maps ID 0 → `_chr_inputs[0]` = the **keyboard** characteristic
  (fixed 8 bytes) and notifies it with 16 bytes.

Net effect: over BLE the host sees a keyboard/mouse; joystick data goes nowhere. (Matches the
"ble fix WIP" commit.)

**Fix:** Use `BLEHidGamepad` (ships in the same library), or subclass
`BLEHidGeneric(1 /*input*/, 0, 0)` and call `setReportMap()` + `setReportLen()` **before**
`begin()`. Note the library writes report-reference IDs starting at 1, so add Report ID 1 to the
descriptor and prepend it consistently.

### B3. Config storage corrupts on second save
`firmware/seedjoy/storage.cpp:66` opens with `FILE_O_WRITE` and never removes/truncates the file.
Verified in `Adafruit_LittleFS_File.cpp`: `FILE_O_WRITE` = `LFS_O_RDWR | LFS_O_CREAT` **plus
seek-to-end** — i.e. append mode, no truncate.

First save works. Every later save appends another whole struct; the file grows to 2×, 3×…
`sizeof(DeviceConfig)`. On next boot the size check (`storage.cpp:103`) fails and the device
**silently reverts to defaults**.

**Fix:** `InternalFS.remove(CONFIG_FILENAME);` before opening for write.

---

## High priority

### H1. BLE connection interval out of spec and silently ignored
Default `bleConnInterval = 2` (2.5 ms) is below the BLE minimum of 6 × 1.25 ms = 7.5 ms.
`sd_ble_gap_ppcp_set` rejects it; the unchecked call at `ble_hid.cpp:94` fails, and the device
actually runs with the library's 11.25–15 ms (set inside `BLEHidAdafruit::begin()`).
Also `config.h:150` comments the field as "7.5ms units" while the code treats it as 1.25 ms units.

**Fix:** clamp to ≥6, check the return value, correct the comment/default (6–12 is sensible).

### H2. BLE config service is wide open
All config/monitor/calibrate characteristics use `SECMODE_OPEN`
(`ble_config.cpp:44-87`). Anyone in radio range can silently rewrite the device config (pins,
name, SR layout) or fire calibration commands — no pairing required.

Related: the comment at `ble_hid.cpp:53-55` claiming security/bonding is "disabled" is wrong —
`setIOCaps(false,false,false)` merely selects Just-Works pairing; the HID characteristics still
require encryption per library defaults.

**Fix:** require encryption (`SECMODE_ENC_NO_MITM`) on write characteristics, and/or gate config
writes behind a physical-button window (the 60 s connect window already exists — reuse it).

### H3. No debounce on shift-register buttons
GPIO buttons are debounced (`buttons.cpp:90-100`); the 56 SR buttons are raw reads shipped at up
to 1 kHz over USB. Mechanical chatter will double-fire in games.

**Fix:** apply the same time-based debounce after `shiftRegisters_.update()` (per-bit last-change
timestamps, or a 2-of-3 vote across reads).

### H4. Battery monitoring is a stub and the math is wrong for XIAO
- `updateBatteryLevel()` (`seedjoy.ino:357-382`) computes a percentage but **never writes
  `blebas_`** — the README's "LiPo voltage → BLE battery service" is not implemented.
- `readVBAT()` never drives `VBAT_ENABLE` (P0.14) LOW, so the XIAO's divider is disconnected and
  the ADC pin floats.
- Compensation factor 2.0 is the Adafruit Feather (100k/100k) value; the XIAO's 1 MΩ/510 kΩ
  divider needs ≈ ×2.96.
- `VBAT_DIVIDER` is defined but unused.

---

## Medium / minor

| # | Issue | Location |
|---|---|---|
| M1 | Mixed-mode button overflow: with any GPIO button enabled, SR offset = 16, so with 7 chips SR buttons map to logical 16–71 and the last 8 silently fall off the 64-bit HID report. | `buttons.cpp:34-48` |
| M2 | Single-char command shortcut consumes any line starting with `C/c/H/h` — fragile if a future command starts with those letters. | `seedjoy.ino:479-489` |
| M3 | Brace-depth framing counts `{`/`}` inside JSON strings — a device name containing a brace breaks config-write reassembly. | `ble_config.cpp:configWriteCallback` |
| M4 | `usbPollRate` only throttles the main loop; the endpoint bInterval is hard-coded to 1 ms in the `Adafruit_USBD_HID` constructor. Conflated concepts. | `usb_hid.cpp:41`, `seedjoy.ino:186` |
| M5 | USB `hidReportCallback` is an empty stub and the GET_REPORT callback is `nullptr` — fine today, but this is the exact plumbing FFB needs (see plan). | `usb_hid.cpp:103-108` |
| M6 | Hand-rolled JSON extraction searches the whole payload per key; nested-scope collisions are avoided today only by careful key naming. Escaped quotes in `deviceName` break parsing. | `.ino` + `ble_config.cpp` |
| M7 | Doc drift: README says D9 = P0.12; `config.h:30` says P1.14 (config.h is correct for XIAO). README's "up to 64 total buttons" contradicts M1. | README, `config.h` |
| M8 | Blocking `Serial` JSON printing in the main loop (button stream, config dump) adds jitter to the 1 kHz report loop — matters much more once an FFB force loop exists. | `seedjoy.ino:214-225` |

---

## What's in good shape

- Clean module separation (axes / buttons / SR / storage / transport); easy to extend.
- Axis pipeline (calibration → deadzone → curve → smoothing) is correct and readable; 12-bit ADC
  configured properly in `axes.begin()`.
- SR read timing is conservative and correct for 74HC165 (≈112 µs for 7 chips — no loop-budget risk).
- Config CRC32 + magic + version validation is sound (once B3 is fixed).
- Ghost-input protection (60 s config window, SR re-init before enabling HID) is thoughtful.
- USB-mode HID input path works as designed (descriptor without report IDs + `sendReport(0, …)` is
  correct TinyUSB usage).

---

## Compile

After the fixes above, the tree builds clean:

```
arduino-cli compile --fqbn Seeeduino:nrf52:xiaonRF52840 .
→ exit 0; Sketch 158064 bytes (19%) flash, 20300 bytes (8%) RAM
```

This closes the B1 blocker (which was a hard compile error) and confirms the B2 BLE type-swap
introduced no build breakage. It does **not** substitute for on-hardware testing: the BLE
enumeration (B2), config persistence across reboots (B3), SR debounce feel (H3), and battery
voltage accuracy (H4 divider constant) still need a flashed device to validate.

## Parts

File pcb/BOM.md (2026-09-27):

# SeedJoy Test Board rev A: parts list (India-sourced)

All parts are through-hole and commonly stocked by Indian hobby-electronics stores. Quantities
are for one board. The links are **store searches** (Indian store pages block automated checks,
so they aren't verified listings). Pick any in-stock item that matches the description.
Fallback for anything out of stock: DigiKey India (digikey.in) or Mouser India (mouser.in),
which ship to India.

Store search shortcuts:
Robu `https://robu.in/?s=<query>&post_type=product` ·
Robocraze `https://robocraze.com/search?q=<query>` ·
Evelta `https://evelta.com/search.php?search_query=<query>`

| Ref | Qty | Part (what to search for) | Notes | Search |
|-----|-----|---|---|---|
| (plugs into J1/J2) | 1 | **Seeed Studio XIAO nRF52840** (non-Sense), SKU 102010448 | Sold by Robu, Robocraze, Evelta. Not the "Sense" or "Plus" variants. Solder its 2×7 male headers if it comes without | [Robu](https://robu.in/?s=XIAO+nRF52840&post_type=product) · [Robocraze](https://robocraze.com/search?q=XIAO+nRF52840) · [Evelta](https://evelta.com/search.php?search_query=XIAO+nRF52840) · [Seeed](https://www.seeedstudio.com/Seeed-XIAO-BLE-nRF52840-p-5201.html) |
| J1, J2 | 2 | 1×7 female header, 2.54 mm | Or cut from a 1×40 female strip | [Robu](https://robu.in/?s=female+header+2.54&post_type=product) |
| U1 | 1 | **74HC165** shift register, DIP-16 | Must be 74**HC**165 (not LS) | [Robu](https://robu.in/?s=74HC165&post_type=product) · [Evelta](https://evelta.com/search.php?search_query=74HC165) |
| U1 socket | 1 | 16-pin DIP IC socket (300 mil) | | [Robu](https://robu.in/?s=16+pin+ic+socket&post_type=product) |
| C1 | 1 | 100 nF ceramic capacitor ("104"), 5 mm lead spacing | | [Robu](https://robu.in/?s=104+ceramic+capacitor&post_type=product) |
| RN1 | 1 | **10 kΩ resistor network, 9-pin SIP, bussed** ("A103J" / "9 pin 10K") | Pin 1 (dot) is the common pin and goes to the square pad | [Robu](https://robu.in/?s=10k+resistor+network+9+pin&post_type=product) · [Evelta](https://evelta.com/search.php?search_query=resistor+network+10k) |
| R1 | 1 | 10 kΩ ¼ W resistor | Chain-input pull-up | [Robu](https://robu.in/?s=10k+resistor+1%2F4w&post_type=product) |
| SW1–SW8 | 8 | 6×6 mm tactile push button, 4-pin THT | Any height | [Robu](https://robu.in/?s=6x6+tactile+switch&post_type=product) |
| SW9 | 1 | 4-position DIP switch, 2.54 mm | | [Robu](https://robu.in/?s=4+way+dip+switch&post_type=product) |
| U2 | 1 | **PS2 2-axis thumbstick (3D rocker potentiometer with push)**. Easiest: buy a **KY-023 / PS2 joystick module** (₹75–150) and desolder its stick | Footprint = Alps RKJXV1224005 pattern. **Before ordering the PCB, check with calipers that the pot pins are 2.5 mm apart** | [Robocraze](https://robocraze.com/products/joystick-module) · [Robomart](https://robomart.com/product/ps2-joystick-module-breakout-sensor/) · [Robu](https://robu.in/?s=ps2+joystick&post_type=product) |
| J3 | 1 | 1×5 female header, 2.54 mm | External analog input: GND, 3V3, X, Y, SW | [Robu](https://robu.in/?s=female+header+2.54&post_type=product) |
| J4–J9 | 1 strip | 2×40 **male** pin header, 2.54 mm. Cut 2× 2×4 (J4, J5), 1×2 (J6), 1×5 (J7), 2× 1×3 (J8, J9) | | [Robu](https://robu.in/?s=2x40+male+header&post_type=product) |
| (on J4, J5, J6, J8, J9) | 5 | 2.54 mm jumper caps (shunts) | Buy a pack | [Robu](https://robu.in/?s=jumper+cap+2.54&post_type=product) |
| H1–H4 | 4 | M3 nylon standoff + screw set | | [Robu](https://robu.in/?s=m3+standoff&post_type=product) |

## Order plan (for someone who already has the XIAO, headers, 74HC165 + socket, R and C)

**Order 1: Sharvi Electronics (everything except the tactile switches)**

| Ref | Buy | Qty (incl. spares) | Link |
|-----|-----|-----|---|
| RN1 | 10k Ohm 9-pin resistor network (SIP) | 2 | [sharvielectronics.com](https://sharvielectronics.com/product/10k-ohm-9-pin-resistor-network-sip/) |
| SW9 | DIP switch, 4 way | 1 | [sharvielectronics.com](https://sharvielectronics.com/product/dip-switch-4-way/) |
| U2 | Dual Axis XY Joystick Module (desolder the stick) | 2 | [sharvielectronics.com](https://sharvielectronics.com/product/dual-axis-xy-joystick-module/) |
| jumpers | Jumper cap 2.54 mm | 6 | [sharvielectronics.com](https://sharvielectronics.com/product/jumper-cap-2-54-mm-pitch-black/) |
| H1–H4 | M3 x 10 mm male-female nylon hex spacer (+ 4 M3 nuts) | 4 | [sharvielectronics.com](https://sharvielectronics.com/product/m3x10mm-male-to-female-nylon-hex-spacer/) |

Buy 2 joystick modules: one to desolder for the paper-fit test (pcb/README.md), one spare.
Don't substitute their "Thumb Joystick Switch XY Dual Axis 4 Way Direction" listing without
checking it: its page gives no specs, and "4-way" may be a digital navigation switch.

**Order 2: Robocraze (tactile switches, 4-pin only)**

| Ref | Buy | Qty | Link |
|-----|-----|-----|---|
| SW1–SW8 | 4-pin DIP 6x6x5 mm tactile switch (pack of 10) | 1 pack | [robocraze.com](https://robocraze.com/products/4-pins-dip-momentary-square-tactile-push-button-switch-10-pieces-6x6x5mm) |

The footprint has **4 pads (6.5 x 4.5 mm)**, so a 2-pin tactile switch won't fit. Sharvi's
6x6x5 "DIP Package" listing is 2-pin; don't use it. Alternative: [Robu 6x6x5 (pack of 20)](https://robu.in/product/6x6x5mm-tactile-push-button-switch-pack-of-20/),
but confirm it's 4-pin in the photos before ordering.

**Backups (if Sharvi is out of stock)**

| Part | Alternatives |
|---|---|
| 10k 9-pin network | [RoboComp](https://robocomp.in/product/10k-ohm-9-pin-resistor-network-sip/), [Kitsguru](https://kitsguru.com/products/a103j-network-resistance-9-pin-10k) |
| 4-way DIP switch | [Robu (pack of 3)](https://robu.in/product/4-way-slide-switch-2-54mm-pitch-pack-of-3/), [REES52](https://rees52.com/products/4-position-dip-switch-rs224) |
| Joystick module | [Robu](https://robu.in/product/joystick-module-ps2-breakout-sensor/), [REES52](https://rees52.com/products/ps2-joystick-module-dual-axis-xy-analog-joystick-breakout), [Robocraze](https://robocraze.com/products/joystick-module) |
| M3 standoffs | [REES52 320-pc M3 nylon kit](https://rees52.com/products/320pcs-m3-male-female-spacer-standoff-kit-320pcs-m3-male-female-nylon-hex-spacer-standoff-screw-nut-assorted-assortment-kit-black-rs1806) |

**PCB:** upload `seedjoy_testboard_gerbers.zip` to JLCPCB or PCBWay (both ship to India).

## Jumper settings

| Jumper | Setting | Effect |
|---|---|---|
| J8 X_SRC | 1-2 | X comes from the on-board stick |
| | 2-3 | X comes from the J3 header (external sensor) |
| J9 Y_SRC | 1-2 / 2-3 | Same, for Y |
| J4 X_SEL | row n | The selected X source goes to An (A0…A3) |
| J5 Y_SEL | row n | The selected Y source goes to An. **Never the same row as J4** |
| J6 | on | Stick push-button (on-board or J3 SW) acts as BTN8 |

Then enable the matching axes in the configurator.

## Notes

- **Chaining your own 74HC165 board (J7):** J7 carries 3V3, GND, CLK (D7), LOAD (D8) and SER-in.
  Wire your chain's last QH to J7 pin 5 (SER). Your chips become buttons 1…8N and this board's
  8 buttons follow. Set *Number of chips* = N + 1. With nothing connected, R1 holds SER high.
- **Everything runs at 3.3 V.** The stick's pots and anything on J3 are powered from 3V3, which
  matches the XIAO's ADC range. Never put 5 V on any pin.
- **Stick push switch** is wired between diagonal legs a and d, so it works whichever way the clone
  pairs its 4 legs internally.
- **Solder order:** IC socket, resistor network, R1, C1, DIP switch, tactile switches, headers,
  thumbstick last. Insert the 74HC165 with its notch matching the silkscreen.
- **PCB:** 2 layers, 1.6 mm FR-4. JLCPCB and PCBWay both ship to India. Upload the Gerber zip.

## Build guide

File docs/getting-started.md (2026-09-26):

# Getting Started with SeedJoy

A step-by-step path from a bare **Seeed Studio XIAO nRF52840** (non-Sense) to a working
controller. The [README](../README.md) is the reference for every detail mentioned here.

## 1. What you need

- Seeed Studio XIAO nRF52840 (the non-Sense board)
- USB-C **data** cable
- 1–7× 74HC165, a 10 kΩ pull-up per button, and the buttons
- Optional: up to 4× 10 kΩ potentiometers, a switch or jumper for D9, a 3.7 V LiPo
- Chrome or Edge for the configurator

## 2. Wire it

Follow [hardware.md](hardware.md). The minimum working setup:

- **One 74HC165**: QH (pin 9) → **D6**, CLK (pin 2) → **D7**, SH/LD (pin 1) → **D8**,
  VCC → **3V3**, GND and CLK INH (pin 15) → GND, SER (pin 10) → **3V3**
- Inputs A–H each with a 10 kΩ pull-up to 3V3 and a button to GND
- Nothing on D9 (boots in USB mode)

## 3. Install the board package

Arduino IDE 2.x: **File → Preferences → Additional Boards Manager URLs**:

```
https://files.seeedstudio.com/arduino/package_seeeduino_boards_index.json
```

Then **Boards Manager → "Seeed nRF52 Boards"** → Install (tested: 1.1.10). Don't use the
*mbed-enabled* package, and don't install extra libraries: TinyUSB, Bluefruit and LittleFS ship
with the core.

## 4. Build and flash

**Arduino IDE:** open `firmware/seedjoy/seedjoy.ino`, choose **Tools → Board → Seeed nRF52
Boards → Seeed XIAO nRF52840**, pick the port, press **Upload**.

**Command line:**

```bash
cd firmware/seedjoy
./compile.sh                    # → build/seedjoy.uf2, .zip, .hex
```

then either `./upload.sh`, or **double-tap RESET** on the XIAO and copy `build/seedjoy.uf2` onto
the USB drive that appears.

On an Apple Silicon Mac without Rosetta, see the README section
"Apple Silicon Macs without Rosetta".

## 5. Check the boot log

Serial Monitor at **115200** baud, then press RESET. The port disappears for a moment around
1 s after boot in USB mode, which is expected. You should see lines like:

```
SeedJoy - BLE/USB Game Controller
Config loaded from Flash            (first boot: "Using default configuration")
Mode select pin: USB (override)
Selected mode: USB
Shift Registers:
  Chips  : 7
...
USB HID initialized successfully
Setup complete!
```

## 6. Set the chip count, then test

1. `cd configurator && python3 -m http.server 8000`, then open **http://localhost:8000**.
2. Choose **🔌 USB Serial** → **Connect Device** → select the XIAO's port.
3. **Read from Device**.
4. **Pin Config**: set *Number of chips* to what you fitted and keep *Invert Logic* ticked.
   **Write to Device**.
5. **Button Mapping**: press buttons and watch the indicators.
6. Check the OS sees a joystick: `joy.cpl` on Windows, `jstest /dev/input/js0` on Linux, or
   https://hardwaretester.com/gamepad.

Axes: wire a pot to A0, enable **Axis 0**, write, then calibrate in **Axis Calibration**.

## 7. Wireless (BLE)

1. Connect D9 to GND (switch or jumper) and press RESET. The log says `Selected mode: BLE`.
2. Pair "SeedJoy" from the OS Bluetooth settings.
3. Input starts **60 s after each connection** (ghost-input protection). Send `H` over serial to
   skip the wait.
4. The configurator's **📡 Bluetooth** mode works in BLE mode too.

## Next

- [hardware.md](hardware.md): full wiring, numbering, battery
- [protocol.md](protocol.md): serial and BLE config protocol
- [troubleshooting.md](troubleshooting.md)

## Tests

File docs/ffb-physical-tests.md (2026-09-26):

# SeedJoy FFB — Physical Test Plan

These are the tests **only you can run**, because they need real USB enumeration, a host OS, and
(for some) a motor. Everything checkable in software is already covered by 67 host-side unit
assertions (`firmware/tests/run_tests.sh` — effect math, the full PID report/handshake path, and a
descriptor structural validator). What remains is the one thing no unit test can prove: **that a
real host accepts the PID descriptor and drives the device**, plus the on-hardware timing/safety and
(optionally) motor behavior.

Work top to bottom — each test gates the next. **Tests 1–7 need NO motor** (force is observed on the
on-board status LED, which mirrors axis-0 |force|). Motor tests are in §8.

Legend: 🔌 = no motor needed · ⚙️ = needs a motor wired · 📈 = better with an oscilloscope/logic analyzer.

---

## 0. Build & flash the FFB firmware

```bash
cd firmware/seedjoy
# Build with FFB enabled (default build has it OFF and is the normal input device)
~/bin/arduino-cli compile --fqbn Seeeduino:nrf52:xiaonRF52840 \
  --build-property "compiler.cpp.extra_flags=-DENABLE_FFB=1" --output-dir build_ffb .
# Flash: make a UF2 and copy it to the bootloader drive (double-tap RESET on the XIAO first):
#   python3 ~/Library/Arduino15/packages/Seeeduino/hardware/nrf52/*/tools/uf2conv/uf2conv.py \
#     -f 0xADA52840 -c -o build_ffb/seedjoy.uf2 build_ffb/seedjoy.ino.hex
# or:
~/bin/arduino-cli upload -p /dev/cu.usbmodem* --fqbn Seeeduino:nrf52:xiaonRF52840 --input-dir build_ffb .
```

- The USB device now identifies as **VID `0x239A`, PID `0x80F5`** (the FFB identity; the non-FFB
  build is `0x80F4`).
- Force select **USB mode**: hold the D9 mode pin HIGH at boot (or connect over USB — see the main
  README). FFB runs in USB mode only.
- **Enable + calibrate at least axis 0 before the force tests.** Axes ship **disabled** (an audit
  safety default), and a disabled axis reports position 0 — so **position/velocity effects (spring,
  damper) produce zero force and a dark LED no matter how you move the pot** until the axis is
  enabled. Do this in the web configurator (enable axis 0, run its min/center/max calibration).
  Constant/sine/ramp don't depend on position, so they'll "work" even with axes disabled — don't let
  that fool you into thinking the spring is broken.
- **Actuator enable:** force output also requires the host to send PID Device Control "enable
  actuators". Linux `hid-pidff` does this automatically when an effect is played (so it's not a
  manual step via `fftest`); only matters if you drive the device from a raw script.

**Tools you'll need** (Linux is the easiest host for FFB bring-up):
- `linuxconsoletools` (provides `fftest`, `jstest`, `evtest`) — `apt install linuxconsoletools`
- `usbutils` (`lsusb`, `usbhid-dump`) and optionally `hidrd` (`hidrd-convert`) for descriptor decode
- `usbmon` + Wireshark (or `tshark`) for the control-transfer handshake
- Windows (optional, later): `joy.cpl`, and `FEdit`/`fedit` from the legacy DirectX SDK

---

## 1. 🔌 Descriptor decodes cleanly

**Purpose:** the descriptor is the single unvalidated artifact. Confirm a real HID parser accepts it
before anything else.

```bash
# Dump the raw HID report descriptor the device advertised:
sudo usbhid-dump -d 239a:80f5 | grep -v : | xxd -r -p > /tmp/seedjoy.rdesc
# Decode it (any of):
hidrd-convert -i natv -o spec /tmp/seedjoy.rdesc      # human-readable
#   ...or paste the bytes into https://eleccelerator.com/usbdescreqparser/
```

**Expected:** decoder reports **no errors**; you can see the Joystick collection (Report ID 1, 4×
16-bit axes + 64 buttons) and a PID collection with report IDs 2–15. Report byte sizes match those
in `ffb_reports.h` (the unit test `ffb_descriptor_test` already checks this against the structs).

- [ ] **PASS / FAIL:** decoder accepts descriptor, no errors → __________

> If FAIL: note the exact item the decoder rejects. This is expected to be the riskiest step; the
> fix is usually a wrong PID *usage* value in `ffb_reports.cpp` (sizes are already test-locked).

## 2. 🔌 Joystick regression (the input device must still work)

**Purpose:** adding the PID collection + Report ID 1 must not break the joystick.

```bash
jstest --normal /dev/input/js0        # or by-id path from: ls /dev/input/by-id/
# move each pot, press buttons
```

**Expected:** 4 axes track the pots; up to 56 buttons register. Windows: `joy.cpl` → Properties
shows the same.

- [ ] **PASS / FAIL:** axes + buttons work with Report ID 1 → __________

## 3. 🔌 PID enumeration + Create→Block Load→Pool handshake

**Purpose:** confirm the OUT endpoint and feature-report handshake work on real USB — the part the
unit tests exercise only through synthetic bytes.

```bash
# Is it recognized as a force-feedback device?
udevadm info -q property /dev/input/event* | grep -i FF        # or:
cat /proc/bus/input/devices                                    # look for "FF" in Handlers/features
# Capture the handshake:
sudo modprobe usbmon
sudo wireshark -k -i usbmon1     # then re-plug the device / start fftest in test 4
```

**Expected:** the device exposes force-feedback capability; in usbmon you see, on effect creation, a
**Create New Effect** feature SET (report 13) followed by a **Block Load** feature GET (report 14)
returning status = 1 (success) and a valid block index, and a **Pool** GET (report 15).

- [ ] **PASS / FAIL:** FF capability present; Block Load returns success → __________

## 4. 🔌 Every effect uploads

**Purpose:** each `Set*` report is parsed and each effect type allocates a block.

```bash
fftest /dev/input/by-id/usb-*SeedJoy*-event-joystick
# In the menu, upload/play each: constant, spring, damper, sine (periodic), ramp, ...
```

**Expected:** every effect uploads without "upload failed"; the pool holds up to 16 concurrent
effects (`MAX_FFB_EFFECTS`) and reports full beyond that.

- [ ] **PASS / FAIL:** all effect types upload → __________

## 5. 🔌📈 Force output is correct (observed on the LED / scope)

The status LED brightness = axis-0 **|force|** (magnitude only; sign needs a motor or a scope on the
DIR pin once wired). Run each from `fftest`.

> **Prerequisite (spring/damper only):** axis 0 must be enabled + calibrated (see §0). A disabled
> axis reports position 0, so spring/damper output is always zero — you'd see a dark LED and wrongly
> conclude the effect is broken.

| Effect | Do this | Expected on the LED |
|---|---|---|
| **Constant** | play a constant force, vary its level | LED brightness tracks the level |
| **Spring** | play a spring, move axis-0 pot off center | LED brightens as displacement grows; **dark at center** |
| **Damper** | play a damper, move the pot fast vs. slow | LED brightens with pot **speed**, dark when still |
| **Sine (periodic)** | play a 2–5 Hz sine | LED **pulses** at that frequency |
| **Ramp** | play a ramp over ~2 s | LED brightness ramps over the duration |

📈 With a scope on a motor PWM pin (after §8) you also confirm **direction/sign**: spring output
opposes displacement; sine alternates direction.

- [ ] **PASS / FAIL:** constant __ · spring centers __ · damper __ · sine freq __ · ramp __

## 6. 🔌 Safety behaviors

**Purpose:** the device must never hold force when it shouldn't.

- **USB detach:** with a constant force playing, unplug USB. → LED goes **dark within ~10 ms**
  (the tick calls `disableAll()` when `TinyUSBDevice.mounted()` is false).
- **PID Device Control:** from `fftest`, stop-all / pause → LED dark; continue → force resumes.
- **Device Gain:** set gain to 50% → LED level roughly halves for the same effect.
- **Global duty clamp:** (optional) rebuild with `-DFFB_MAX_DUTY=0.5f`; max LED brightness caps at
  ~half even at full effect + full gain.

- [ ] **PASS / FAIL:** detach kills output __ · pause/stop __ · gain scales __ · duty clamp __

## 7. 🔌 Concurrency stress (validates the mutex fix)

**Purpose:** the one property that can't be unit-tested — the `usbd`-task callbacks vs. the `loop`
tick are serialized by `ffb_lock` and never hang or glitch under load.

```bash
# Hammer effect parameter updates while a force loop runs. Option A: a loop of fftest uploads.
# Option B (better), a tiny SDL2 haptic program updating a constant effect's level every ~2 ms
# for a few minutes while you watch the LED and dmesg.
dmesg -w    # watch for USB errors/timeouts in another terminal
```

**Expected:** runs for minutes with **no USB stalls, no device reset, no LED freeze/glitch**; the
force keeps responding. A hang or `dmesg` USB timeout would indicate a lock/ordering bug.

- [ ] **PASS / FAIL:** sustained upload load, no stall/glitch → __________

---

## 8. ⚙️ Motor bring-up (Phase 4)

Only after §1–7 pass. **No motor pins are assigned by default** — you must choose a driver and edit
`firmware/seedjoy/ffb_motor.cpp::begin()`. Recommended first rig: one axis, DRV8871.

```cpp
// in MotorOutput::begin()
axis_[0].type   = MOTOR_DRIVER_DUAL_PWM;  // DRV8871 IN1/IN2
axis_[0].pinA   = D4;                      // IN1
axis_[0].pinB   = D5;                      // IN2
axis_[0].invert = false;                   // set true if the spring pushes AWAY from center
```

**Electrical (do not skip):** separate motor supply sized for stall current, **common ground** with
the XIAO, flyback/TVS protection. Start with `-DFFB_MAX_DUTY=0.3f` and a small motor.

**Safety first:** confirm §6 detach test **with the motor wired** — unplug USB, motor must go limp
immediately.

Then re-run §5 on the motor:
- [ ] ⚙️ **Constant** — motor pushes one way, reverses with sign
- [ ] ⚙️ **Spring** — release off-center, motor **centers** the axis (if it pushes away, flip `invert`)
- [ ] ⚙️ **Damper** — axis feels heavier when moved fast
- [ ] ⚙️ **Sine** — motor oscillates at the effect frequency
- [ ] ⚙️ Direction/sign matches the game (tune `invert` / the polar-direction mapping)

**Windows validation (optional, after Linux is clean):** `joy.cpl` shows the device; `FEdit` (legacy
DirectX SDK) creates/plays effects. Windows' PID driver is stricter than Linux — if Linux passes but
Windows rejects enumeration, the descriptor's Block Load status codes / Pool report are the usual
culprits.

---

## Results summary (fill in)

| # | Test | Motor? | Result | Notes |
|---|---|---|---|---|
| 1 | Descriptor decodes | no | | |
| 2 | Joystick regression | no | | |
| 3 | PID enum + handshake | no | | |
| 4 | Effects upload | no | | |
| 5 | Force correctness (LED) | no | | |
| 6 | Safety | no | | |
| 7 | Concurrency stress | no | | |
| 8 | Motor bring-up | yes | | |

Send this back with the FAIL rows filled in (and the decoder output / usbmon capture for any failure)
and I can turn each into a specific firmware fix.

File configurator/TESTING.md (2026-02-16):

# Web Configurator Testing Guide

## Current Status

✅ **Working:**
- WebBluetooth device discovery and connection
- Battery level monitoring
- UI for pin configuration, calibration, button mapping
- Export/import configuration files
- Configuration state management in browser

⏳ **In Progress:**
- BLE GATT configuration service (firmware side)
- Read/write device configuration over BLE
- Real-time axis/button state monitoring

## How to Test

### 1. Start Local Server

The web configurator requires HTTPS for WebBluetooth (security requirement).

**Option A: Python HTTPS Server (using localhost exception)**
```bash
cd configurator
python3 -m http.server 8000
```
Then open: http://localhost:8000

**Option B: Using mkcert for proper HTTPS**
```bash
# Install mkcert (one-time)
brew install mkcert
mkcert -install

# Generate local certificates (one-time)
cd configurator
mkcert localhost 127.0.0.1 ::1

# Serve with HTTPS (requires Node.js)
npx http-server -S -C localhost+2.pem -K localhost+2-key.pem -p 8443
```
Then open: https://localhost:8443

### 2. Open in Chrome/Edge

WebBluetooth is only supported in:
- Chrome 56+
- Edge 79+
- Opera 43+

**NOT supported:** Firefox, Safari (as of Feb 2026)

### 3. Connect to Device

1. Make sure XIAO nRF52840 is powered and running SeedJoy firmware in BLE mode
2. Click "Connect Device" button
3. Select "SeedJoy" from the Bluetooth device list
4. Should connect successfully

**If you get "blocklisted UUID" error:**
- This is fixed in the latest version of ble.js
- Make sure you're using the updated code (HID UUID moved to optionalServices)

### 4. What Works Now

✅ **Battery monitoring:** Should display current battery level

✅ **UI interaction:** All tabs and settings work locally

✅ **Export/import:** Can save/load configuration as JSON file

❌ **Read device config:** Shows "not available" message

❌ **Write device config:** Shows "not available" message

❌ **Live axis monitoring:** Requires config service

### 5. Test Configuration Locally

1. Modify pin assignments in the UI
2. Adjust axis calibration settings
3. Map buttons
4. Click "Export Configuration"
5. Save JSON file
6. Click "Import Configuration" 
7. Load the JSON file
8. Verify settings are restored

## Next Steps (Firmware Development)

To enable full configuration functionality, the firmware needs:

1. **Add Custom GATT Service:**
   ```cpp
   // In ble_hid.h
   BLEService configService_;
   BLECharacteristic configReadCharacteristic_;
   BLECharacteristic configWriteCharacteristic_;
   BLECharacteristic configStatusCharacteristic_;
   ```

2. **Define Service UUIDs:**
   ```cpp
   #define CONFIG_SERVICE_UUID "e95d0001-251d-470a-a062-fa1922dfa9a8"
   #define CONFIG_CHAR_UUID    "e95d0002-251d-470a-a062-fa1922dfa9a8"
   #define STATUS_CHAR_UUID    "e95d0003-251d-470a-a062-fa1922dfa9a8"
   ```

3. **Implement Read/Write Handlers:**
   - Handle config read requests (serialize DeviceConfig to JSON)
   - Handle config write requests (deserialize and validate JSON)
   - Update Flash storage when config changes

4. **Add to Advertising:**
   ```cpp
   Bluefruit.Advertising.addService(configService_);
   ```

## Troubleshooting

**"WebBluetooth not supported"**
- Use Chrome, Edge, or Opera
- Update browser to latest version

**"User cancelled the requestDevice() chooser"**
- User clicked cancel - expected behavior

**"Connection failed"**
- Make sure device is in BLE mode (not USB)
- Check device is powered on
- Try resetting the XIAO board

**"Config service not available"**
- Expected - firmware doesn't implement it yet
- Can still uselocal configurator features

**HTTPS required error**
- localhost exception should work
- Otherwise use mkcert for local HTTPS certificates

## Developer Console

Open browser DevTools (F12) and check Console tab for:
- Connection status messages
- Service discovery results
- Error details

Example successful connection:
```
Requesting Bluetooth device...
Device selected: SeedJoy-1234
Connecting to GATT server...
Connected to GATT server
Battery service connected, level: 100%
⚠️  Config service not available
    Configuration service not yet implemented in firmware
```

## Configuration File Format

The exported JSON configuration looks like:
```json
{
  "magic": 1592942775,
  "configVersion": 1,
  "deviceName": "SeedJoy",
  "mode": 1,
  "axes": [...],
  "buttons": [...],
  "shiftRegisters": {...},
  "usbVID": 9114,
  "usbPID": 32980,
  ...
}
```

You can manually edit this file and import it.

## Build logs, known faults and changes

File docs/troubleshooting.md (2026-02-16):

# SeedJoy Troubleshooting Guide

## Configuration Mode Issues

### Issue: Unwanted Keystrokes/Mouse Movements During BLE Configuration

**Problem:**
When connecting to SeedJoy via Bluetooth using the web configurator, you may experience:
- Random mouse movements
- Unwanted keystrokes
- Microphone permission dialog appearing
- System behaving as if a gamepad is active

**Root Cause:**
The device advertises itself as a Bluetooth HID (Human Interface Device) gamepad and immediately starts sending HID reports upon connection. If analog input pins are floating (not connected to potentiometers) or have electrical noise, they produce random values that the operating system interprets as joystick movements or button presses.

**Solution:**
The firmware now includes a **Configuration Mode** that automatically disables HID input reporting for 10 seconds after a BLE connection is established. This gives you time to safely connect the configurator without triggering unwanted HID events.

### Configuration Mode Behavior

1. **Automatic Activation**: When a device connects via BLE, Configuration Mode is automatically enabled for 10 seconds
2. **HID Reports Disabled**: During this time, no HID gamepad reports are sent to the host computer
3. **Visual Feedback**: The configurator displays a notification explaining that Configuration Mode is active
4. **Auto-Enable**: After 10 seconds, HID reporting automatically resumes unless:
   - The MODE button is held down (keeps Configuration Mode active)
   - Serial command `C` is sent (resets the 10-second timer)

### Manual Control

You can manually control Configuration Mode using these methods:

#### Serial Commands (via USB Serial Monitor)
- **`C`** - Enter Configuration Mode (disable HID, reset timeout)
- **`H`** - Enable HID Mode immediately
- **`?`** - Show help menu

#### Hardware Button
- **Hold MODE button** - Keeps device in Configuration Mode as long as button is pressed

### Usage Tips

1. **First Connection**: Simply connect via the web configurator - Configuration Mode activates automatically
2. **Extended Configuration**: If you need more than 10 seconds, hold the MODE button during configuration
3. **Quick Enable**: To enable HID immediately after connecting, send `H` via serial or wait for timeout
4. **Preventing Issues**: Always connect to the configurator first before using the device as a gamepad

### Debug Serial Output

When connected via BLE, the serial monitor will show:
```
=======================================
BLE CONNECTED - Configuration Mode Active
HID reports disabled for 10 seconds
Hold MODE button or send 'C' via serial to stay in config mode
Send 'H' to enable HID mode immediately
=======================================
```

### Technical Details

The fix implements:
- `hidEnabled_` flag in `BLEHIDController` class
- `setHIDEnabled()` method to control HID report transmission
- Automatic zero-report sent when disabling HID (clears any stuck inputs)
- Timer-based auto-enable after 10 seconds
- Button and serial command overrides

### Related Files
- Firmware: `firmware/seedjoy/ble_hid.cpp`, `firmware/seedjoy/ble_hid.h`, `firmware/seedjoy/seedjoy.ino`
- Configurator: `configurator/app.js`

## Other Common Issues

### Device Not Showing in Bluetooth Scan
- Ensure `DEV_FORCE_BLE_MODE` is set to `1` in `seedjoy.ino` (for development)
- Check that MODE select pin is LOW (pull to ground)
- Verify the device is powered on and STATUS LED is visible
- Some browsers require HTTPS for Web Bluetooth - use Chrome/Edge

### Configuration Not Saving
- Configuration service is not yet fully implemented in firmware (v0.1.0)
- Current workaround: Settings are saved in browser's localStorage
- Future updates will add persistent storage via BLE characteristic writes

### Battery Level Not Updating
- Battery service requires LiPo battery connected to charging circuit
- Reading shows 100% if USB powered without battery
- Check voltage on VBAT pin for accurate reading

## Getting Help

If you encounter issues not covered here:
1. Check serial monitor output for error messages
2. Verify firmware version matches configurator version
3. Review hardware connections (especially analog inputs)
4. Submit issue on GitHub with serial output logs

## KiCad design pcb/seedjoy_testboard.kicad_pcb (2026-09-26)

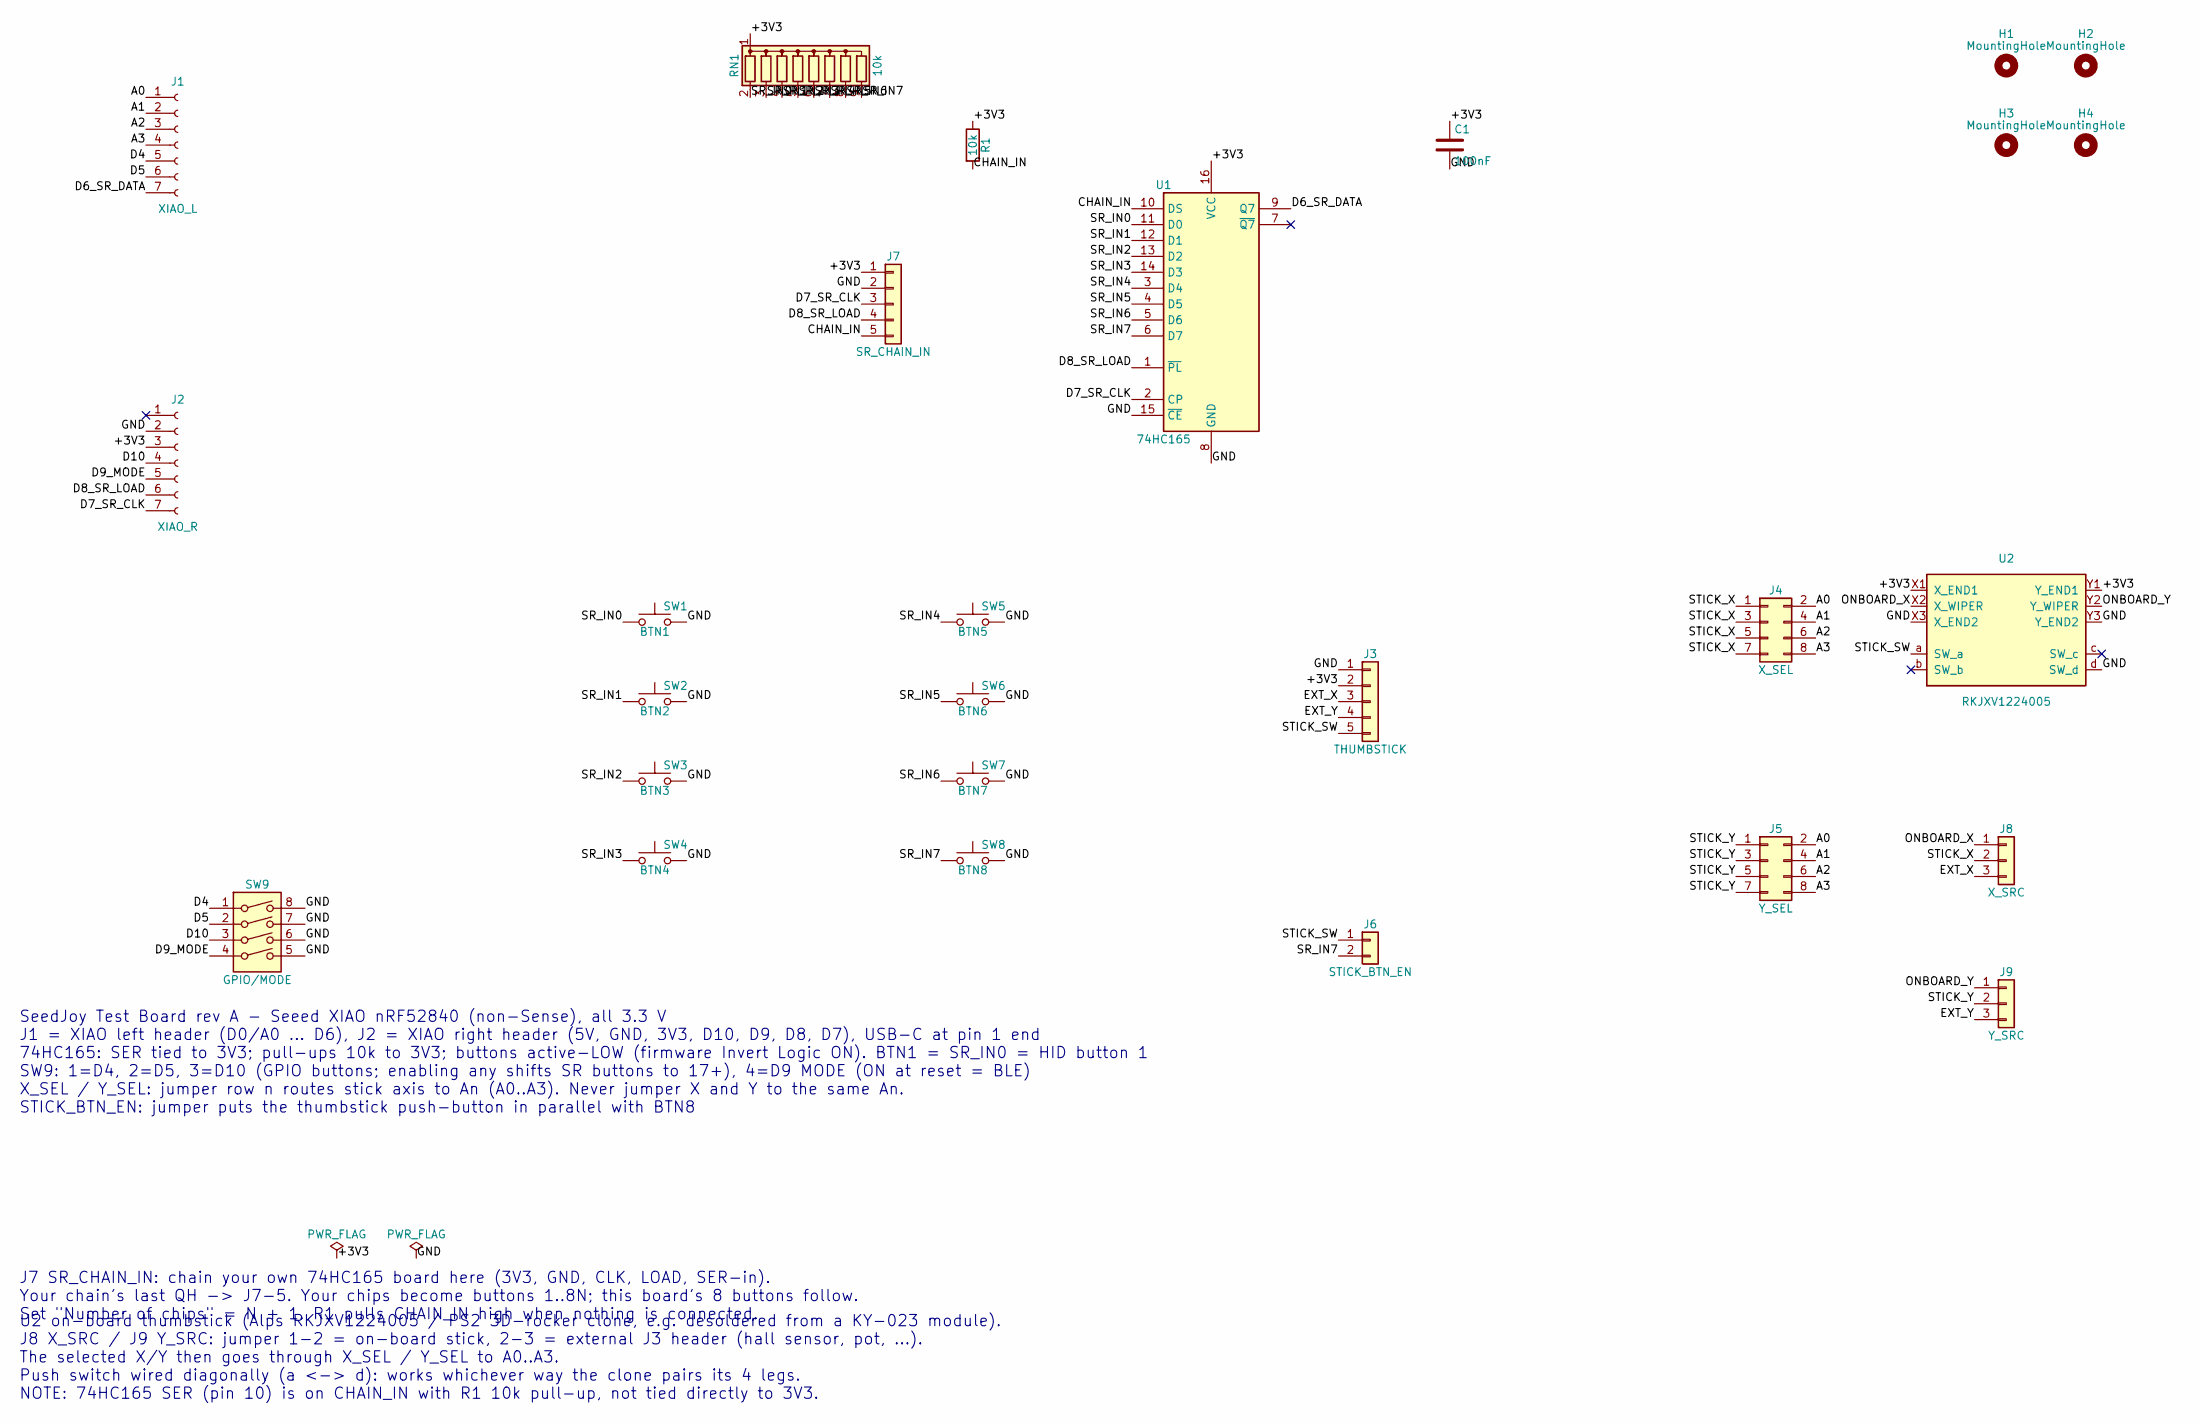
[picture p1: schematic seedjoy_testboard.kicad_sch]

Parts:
C1: 100nF; C_Disc_D5.0mm_W2.5mm_P5.00mm
H1, H2, H3, H4: MountingHole; MountingHole_3.2mm_M3
J1: XIAO_L; PinSocket_1x07_P2.54mm_Vertical
J2: XIAO_R; PinSocket_1x07_P2.54mm_Vertical
J3: THUMBSTICK; PinHeader_1x05_P2.54mm_Vertical
J4: X_SEL; PinHeader_2x04_P2.54mm_Vertical
J5: Y_SEL; PinHeader_2x04_P2.54mm_Vertical
J6: STICK_BTN_EN; PinHeader_1x02_P2.54mm_Vertical
J7: SR_CHAIN_IN; PinHeader_1x05_P2.54mm_Vertical
J8: X_SRC; PinHeader_1x03_P2.54mm_Vertical
J9: Y_SRC; PinHeader_1x03_P2.54mm_Vertical
R1: 10k; R_Axial_DIN0207_L6.3mm_D2.5mm_P10.16mm_Horizontal
RN1: 10k; R_Array_SIP9
SW1: BTN1; SW_PUSH_6mm_H5mm
SW2: BTN2; SW_PUSH_6mm_H5mm
SW3: BTN3; SW_PUSH_6mm_H5mm
SW4: BTN4; SW_PUSH_6mm_H5mm
SW5: BTN5; SW_PUSH_6mm_H5mm
SW6: BTN6; SW_PUSH_6mm_H5mm
SW7: BTN7; SW_PUSH_6mm_H5mm
SW8: BTN8; SW_PUSH_6mm_H5mm
SW9: GPIO/MODE; SW_DIP_SPSTx04_Slide_9.78x12.34mm_W7.62mm_P2.54mm
U1: 74HC165; DIP-16_W7.62mm_Socket
U2: RKJXV1224005; Alps_RKJXV1224005_Thumbstick

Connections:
/+3V3: C1.1, J2.3, J3.2, J7.1, R1.1, RN1.1 (common), U1.16 (VCC), U2.X1 (X_END1), U2.Y1 (Y_END1)
/A0: J1.1, J4.2, J5.2
/A1: J1.2, J4.4, J5.4
/A2: J1.3, J4.6, J5.6
/A3: J1.4, J4.8, J5.8
/CHAIN_IN: J7.5, R1.2, U1.10 (DS)
/D4: J1.5, SW9.1
/D5: J1.6, SW9.2
/D6_SR_DATA: J1.7, U1.9 (Q7)
/D7_SR_CLK: J2.7, J7.3, U1.2 (CP)
/D8_SR_LOAD: J2.6, J7.4, U1.1 (~PL)
/D9_MODE: J2.5, SW9.4
/D10: J2.4, SW9.3
/EXT_X: J3.3, J8.3
/EXT_Y: J3.4, J9.3
/GND: C1.2, J2.2, J3.1, J7.2, SW1.2, SW2.2, SW3.2, SW4.2, SW5.2, SW6.2, SW7.2, SW8.2, SW9.5, SW9.6, SW9.7, SW9.8, U1.8 (GND), U1.15 (~CE), U2.X3 (X_END2), U2.Y3 (Y_END2), U2.d (SW_d)
/ONBOARD_X: J8.1, U2.X2 (X_WIPER)
/ONBOARD_Y: J9.1, U2.Y2 (Y_WIPER)
/SR_IN0: RN1.2 (R1), SW1.1, U1.11 (D0)
/SR_IN1: RN1.3 (R2), SW2.1, U1.12 (D1)
/SR_IN2: RN1.4 (R3), SW3.1, U1.13 (D2)
/SR_IN3: RN1.5 (R4), SW4.1, U1.14 (D3)
/SR_IN4: RN1.6 (R5), SW5.1, U1.3 (D4)
/SR_IN5: RN1.7 (R6), SW6.1, U1.4 (D5)
/SR_IN6: RN1.8 (R7), SW7.1, U1.5 (D6)
/SR_IN7: J6.2, RN1.9 (R8), SW8.1, U1.6 (D7)
/STICK_SW: J3.5, J6.1, U2.a (SW_a)
/STICK_X: J4.1, J4.3, J4.5, J4.7, J8.2
/STICK_Y: J5.1, J5.3, J5.5, J5.7, J9.2

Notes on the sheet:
SeedJoy Test Board rev A - Seeed XIAO nRF52840 (non-Sense), all 3.3 V J1 = XIAO left header (D0/A0 ... D6), J2 = XIAO right header (5V, GND, 3V3, D10, D9, D8, D7), USB-C at pin 1 end 74HC165: SER tied to 3V3; pull-ups 10k to 3V3; buttons active-LOW (firmware Invert Logic ON). BTN1 = SR_IN0 = HID bu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
J7 SR_CHAIN_IN: chain your own 74HC165 board here (3V3, GND, CLK, LOAD, SER-in). Your chain's last QH -> J7-5. Your chips become buttons 1..8N; this board's 8 buttons follow. Set "Number of chips" = N + 1. R1 pulls CHAIN_IN high when nothing is connected.
U2 on-board thumbstick (Alps RKJXV1224005 / PS2 3D-rocker clone, e.g. desoldered from a KY-023 module). J8 X_SRC / J9 Y_SRC: jumper 1-2 = on-board stick, 2-3 = external J3 header (hall sensor, pot, ...). The selected X/Y then goes through X_SEL / Y_SEL to A0..A3. Push switch wired diagonally (a <->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

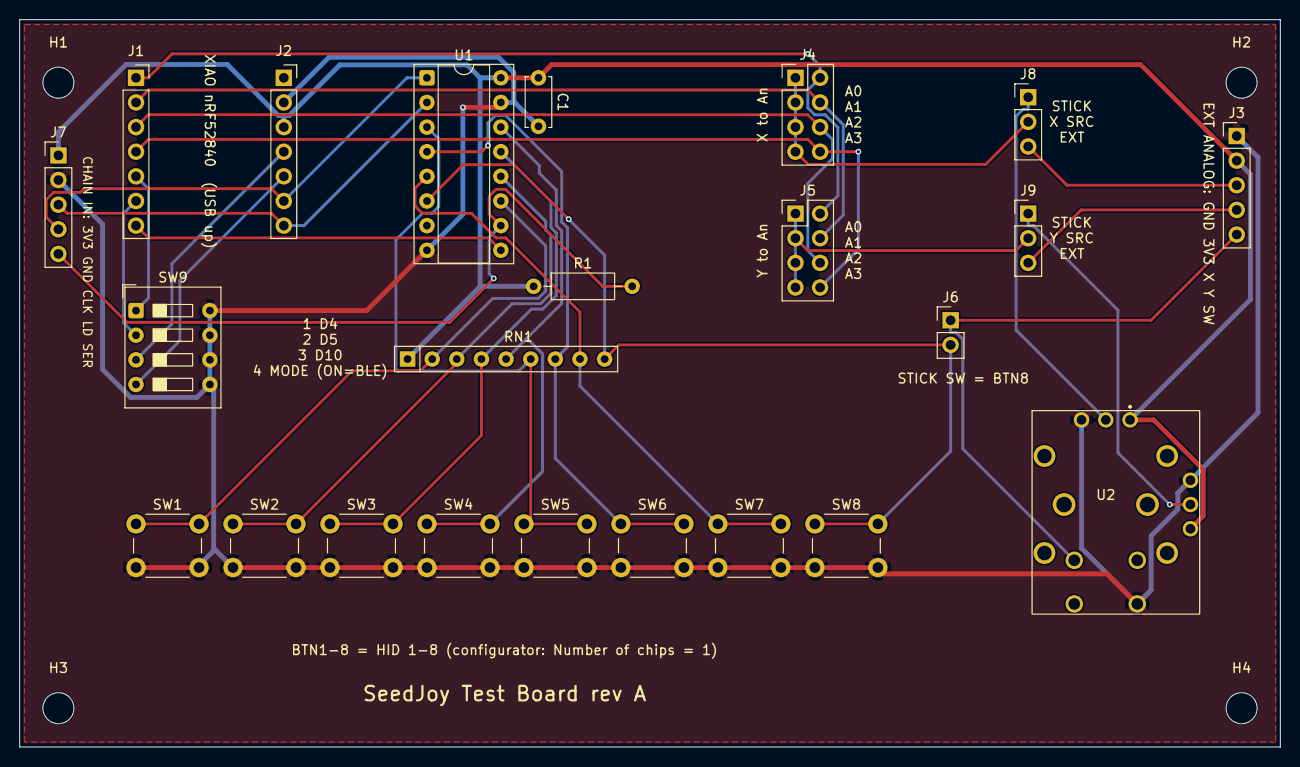
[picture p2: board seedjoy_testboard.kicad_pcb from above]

Board: 2 copper layers, 130.0 x 75.0 mm, 27 parts (0 on the bottom side), 29 nets.

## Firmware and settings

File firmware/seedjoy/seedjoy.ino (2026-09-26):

/**
 * SeedJoy - Main Firmware
 * 
 * Dual-mode (USB/BLE) game controller for Seeed Studio XIAO nRF52840
 * 
 * Features:
 * - 4 analog axes with calibration and curves
 * - Up to 56 buttons via 74HC165 shift registers (debounced)
 * - Boot-time mode selection on D9 (USB or BLE)
 * - Web-based configuration via Web Serial or WebBluetooth
 * - Persistent configuration in Flash (LittleFS)
 *
 * Hardware:
 * - Seeed Studio XIAO nRF52840
 * - 4x potentiometers on A0-A3
 * - 74HC165 chain on D6 (data) / D7 (clock) / D8 (load)
 * - Mode select on D9 (floating/HIGH = USB, GND at boot = BLE)
 */

// Development flags
#define DEV_FORCE_BLE_MODE 0 // Set to 1 to force BLE mode, 0 for normal operation

#include "config.h"
#include "storage.h"
#include "axes.h"
#include "buttons.h"
#include "usb_hid.h"
#include "ble_hid.h"
#include "ble_config.h"
#if ENABLE_FFB
#include "ffb_runtime.h"
#include "ffb_motor.h"
#include "ffb_lock.h"
#endif

// Global objects
DeviceConfig deviceConfig;
StorageManager storage;
AxesProcessor axes;
ButtonsProcessor buttons;
USBHIDController usbHID;
BLEHIDController bleHID;
BLEConfigService bleConfig;

#if ENABLE_FFB
// Force feedback runs in USB mode only (see docs/ffb-plan.md). The engine is
// unit-tested (firmware/tests); the USB PID descriptor/handshake is NOT yet
// hardware-validated.
FfbRuntime ffbRuntime;
MotorOutput ffbMotor;
uint32_t lastFfbTick = 0;
void updateFFB();
#endif

// Current operation mode
OperationMode currentMode = MODE_USB;

// Configuration mode for BLE (prevents HID reports during setup)
bool configurationMode = false;
uint32_t bleConnectionTime = 0;
const uint32_t CONFIG_MODE_TIMEOUT = 60000; // 60 seconds after connection (was 10s - extended for safety)
bool wasConnected = false;
bool serialButtonStream = false;   // true while browser is on the Button Mapping tab
uint32_t lastButtonStreamTime = 0; // rate-limit to ~20 Hz
bool serialAxisStream = false;     // true while browser is on the Axis Calibration tab
uint32_t lastAxisStreamTime = 0;   // rate-limit to ~20 Hz

// Battery monitoring (XIAO nRF52840)
// Read PIN_VBAT (P0.31) with VBAT_ENABLE (P0.14) driven LOW to connect the
// on-board divider, using the 3.0V ADC reference.
#define VBAT_PIN PIN_VBAT
#define VBAT_MV_PER_LSB (0.73242188F)  // 3.0V ADC range / 4096 (requires AR_INTERNAL_3_0)
// Compensation for the XIAO's 1M / 0.51M divider: 1/(0.51/1.51) ≈ 2.96.
// This is board-specific and NOT defined in the BSP — calibrate against a
// multimeter if the reported voltage looks off (the % is a rough estimate anyway).
#define VBAT_DIVIDER_COMP (2.96F)

// Timing
uint32_t lastReportTime = 0;
uint32_t lastBatteryCheck = 0;
const uint32_t BATTERY_CHECK_INTERVAL = 60000; // Check every 60 seconds

// Function prototypes
void selectOperationMode();
void initializeHardware();
void updateInputs();
void sendHIDReports();
void updateBatteryLevel();
float readVBAT();
void blinkStatus(int times);

void setup() {
  // Initialize serial for debugging
  Serial.begin(115200);
  
  // Wait a bit for serial to initialize (optional)
  delay(1000);
  
  Serial.println("=================================");
  Serial.println("SeedJoy - BLE/USB Game Controller");
  Serial.print("Firmware v");
  Serial.print(FIRMWARE_VERSION_MAJOR);
  Serial.print(".");
  Serial.print(FIRMWARE_VERSION_MINOR);
  Serial.print(".");
  Serial.println(FIRMWARE_VERSION_PATCH);
  Serial.println("=================================");
  
  // Initialize LEDs
  pinMode(STATUS_LED_PIN, OUTPUT);
  pinMode(CONNECTION_LED_PIN, OUTPUT);
  digitalWrite(STATUS_LED_PIN, LED_ON);  // Turn on status LED during init
  digitalWrite(CONNECTION_LED_PIN, LED_OFF);

  // Hold the battery divider's low side LOW from boot (see readVBAT()).
  pinMode(VBAT_ENABLE, OUTPUT);
  digitalWrite(VBAT_ENABLE, LOW);

  // Initialize storage
  Serial.println("Initializing storage...");
  storage.begin();
  
  // Load configuration
  Serial.println("Loading configuration...");
  if (!storage.loadConfig(&deviceConfig)) {
    Serial.println("Using default configuration");
    // Save default config
    storage.saveConfig(&deviceConfig);
  }
  
  Serial.print("Device name: ");
  Serial.println(deviceConfig.deviceName);
  Serial.print("Config mode: ");
  Serial.println(deviceConfig.mode == MODE_USB ? "USB" : 
                 deviceConfig.mode == MODE_BLE ? "BLE" : "AUTO");
  
  // Select operation mode (read mode select button)
  selectOperationMode();
  
  // Initialize hardware components
  initializeHardware();
  
  // Initialize appropriate HID interface
  if (currentMode == MODE_USB) {
    Serial.println("Starting USB HID...");
#if ENABLE_FFB
    // Create the FFB mutex and register the runtime BEFORE begin(), so the lock
    // exists before the usbd task can fire a report callback.
    ffbLockInit();
    ffbRuntime.engine().setMaxOutput(FFB_MAX_DUTY);   // global safety clamp
    usbHID.setFfbRuntime(&ffbRuntime);
#endif
    if (usbHID.begin(&deviceConfig)) {
      Serial.println("USB HID initialized successfully");
      digitalWrite(STATUS_LED_PIN, LED_OFF);   // Turn off status LED
      digitalWrite(CONNECTION_LED_PIN, LED_ON); // Turn on connection LED
#if ENABLE_FFB
      ffbMotor.begin();
      Serial.println("FFB runtime active (USB PID) - UNVALIDATED, see docs/ffb-plan.md");
#endif
    } else {
      Serial.println("USB HID initialization failed!");
      blinkStatus(5); // Blink 5 times to indicate error
    }
  } else if (currentMode == MODE_BLE) {
    Serial.println("========================================");
    Serial.println("       INITIALIZING BLE MODE");
    Serial.println("========================================");
    
    if (bleHID.begin(&deviceConfig)) {
      Serial.println("BLE HID initialized successfully");
      
      // Initialize BLE config service BEFORE starting advertising
      Serial.println("");
      Serial.println("Starting BLE Config Service...");
      if (bleConfig.begin(&deviceConfig, &storage, &axes)) {
        Serial.println("BLE Config Service initialized successfully");
        // Provide ButtonsProcessor to BLE config service for real-time button monitoring
        bleConfig.setButtonsProcessor(&buttons);
      } else {
        Serial.println("BLE Config Service initialization failed!");
      }
      
      // NOW start advertising (after all services are initialized)
      // Pass config service so it's included in advertising packet for WebBluetooth discovery
      Serial.println("");
      Serial.println("Starting BLE advertising...");
      bleHID.startAdvertising(&bleConfig.getService());
      Serial.println("Waiting for connection...");
      Serial.println("========================================");
      Serial.println("");
      digitalWrite(STATUS_LED_PIN, LED_OFF);   // Turn off status LED
      // Connection LED will be controlled by BLE connection status
    } else {
      Serial.println("BLE HID initialization failed!");
      blinkStatus(5);
    }
  }
  
  Serial.println("Setup complete!");
  Serial.println("========================================");
  Serial.println("");
  Serial.println("=================================");
}

void loop() {
  // Handle BLE configuration mode
  if (currentMode == MODE_BLE) {
    handleBLEConfigMode();
  }
  
  // Check for serial commands
  if (Serial.available()) {
    handleSerialCommand();
  }
  
  // Update all inputs
  updateInputs();

#if ENABLE_FFB
  // Force-feedback loop (USB mode only).
  if (currentMode == MODE_USB) {
    updateFFB();
  }
#endif

  // Send HID reports at configured poll rate
  uint32_t now = millis();
  uint32_t reportInterval = deviceConfig.usbPollRate; // 1ms for USB, can be adjusted
  
  if (currentMode == MODE_BLE) {
    // For BLE, send reports at a reasonable rate (e.g., every 8ms for ~125Hz)
    reportInterval = 8;
  }
  
  if (now - lastReportTime >= reportInterval) {
    sendHIDReports();
    lastReportTime = now;
  }
  
  // Update battery level periodically (BLE only)
  if (currentMode == MODE_BLE && now - lastBatteryCheck >= BATTERY_CHECK_INTERVAL) {
    updateBatteryLevel();
    lastBatteryCheck = now;
  }
  
  // Update connection LED for BLE
  if (currentMode == MODE_BLE) {
    digitalWrite(CONNECTION_LED_PIN, bleHID.isConnected() ? LED_ON : LED_OFF);
    
    // Update axis monitoring for configurator (only when connected)
    if (bleHID.isConnected()) {
      bleConfig.updateAxisMonitoring();
    }
  }
  
  // Stream button states over Serial for the Web Serial button-test tab (~20 Hz)
  if (serialButtonStream && (now - lastButtonStreamTime >= 50)) {
    uint8_t bBytes[8];
    buttons.getExtendedButtonStates(bBytes, 8);
    Serial.print("{\"type\":\"buttons\",\"data\":{\"states\":[");
    for (int bi = 0; bi < 8; bi++) {
      if (bi > 0) Serial.print(",");
      Serial.print(bBytes[bi]);
    }
    Serial.println("]}}");
    lastButtonStreamTime = now;
  }

  // Stream raw + processed axis values for the Web Serial calibration tab (~20 Hz)
  if (serialAxisStream && (now - lastAxisStreamTime >= 50)) {
    Serial.print("{\"type\":\"axes\",\"data\":{\"raw\":[");
    for (int ai = 0; ai < MAX_AXES; ai++) {
      if (ai > 0) Serial.print(",");
      Serial.print(axes.getRawValue(ai));
    }
    Serial.print("],\"processed\":[");
    for (int ai = 0; ai < MAX_AXES; ai++) {
      if (ai > 0) Serial.print(",");
      Serial.print(axes.getAxisValue(ai));
    }
    Serial.println("]}}");
    lastAxisStreamTime = now;
  }

  // Small delay to prevent tight looping (optional)
  // delayMicroseconds(100);
}

void selectOperationMode() {
#if DEV_FORCE_BLE_MODE
  // Development mode: Force BLE for testing
  currentMode = MODE_BLE;
  Serial.println(">>> DEVELOPMENT MODE: Forced BLE <<<");
  Serial.println("(Set DEV_FORCE_BLE_MODE to 0 to restore normal operation)");
  return;
#endif

  // Read mode select pin
  pinMode(MODE_SELECT_PIN, INPUT_PULLUP);
  delay(10); // Debounce
  
  bool modeSelectHigh = digitalRead(MODE_SELECT_PIN) == HIGH;
  
  // Check config mode setting
  if (deviceConfig.mode == MODE_AUTO) {
    // Auto mode: prefer USB if connected, otherwise BLE
    // For now, default to USB in AUTO mode
    currentMode = MODE_USB;
    Serial.println("AUTO mode: defaulting to USB");
  } else if (deviceConfig.mode == MODE_USB) {
    currentMode = MODE_USB;
    Serial.println("Config mode: USB");
  } else if (deviceConfig.mode == MODE_BLE) {
    currentMode = MODE_BLE;
    Serial.println("Config mode: BLE");
  }
  
  // Mode select pin override (for manual switching)
  // HIGH = USB, LOW = BLE
  if (modeSelectHigh) {
    Serial.println("Mode select pin: USB (override)");
    currentMode = MODE_USB;
  } else {
    Serial.println("Mode select pin: BLE (override)");
    currentMode = MODE_BLE;
  }
  
  Serial.print("Selected mode: ");
  Serial.println(currentMode == MODE_USB ? "USB" : "BLE");
}

void initializeHardware() {
  Serial.println("Initializing axes...");
  axes.begin(&deviceConfig);
  
  Serial.println("Initializing buttons...");
  buttons.begin(&deviceConfig);
  
  // Print pin configuration
  Serial.println("\nPin Configuration:");
  Serial.println("Axes:");
  for (int i = 0; i < MAX_AXES; i++) {
    if (deviceConfig.axes[i].enabled) {
      Serial.print("  Axis ");
      Serial.print(i);
      Serial.print(": Pin ");
      Serial.print(deviceConfig.axes[i].pin);
      Serial.print(" (");
      Serial.print(deviceConfig.axes[i].inverted ? "inverted" : "normal");
      Serial.println(")");
    }
  }
  
  Serial.println("Buttons (GPIO):");
  bool anyGpio = false;
  for (int i = 0; i < MAX_BUTTONS; i++) {
    if (deviceConfig.buttons[i].enabled) {
      anyGpio = true;
      Serial.print("  Button ");
      Serial.print(i);
      Serial.print(": Pin ");
      Serial.print(deviceConfig.buttons[i].pin);
      Serial.print(" -> Logical ");
      Serial.println(deviceConfig.buttons[i].logicalNumber);
    }
  }
  if (!anyGpio) Serial.println("  (none enabled - SR-only mode)");

  Serial.println("Shift Registers:");
  if (deviceConfig.shiftRegisters.enabled) {
    Serial.print("  Chips  : "); Serial.println(deviceConfig.shiftRegisters.numChips);
    Serial.print("  Buttons: "); Serial.println(deviceConfig.shiftRegisters.numChips * 8);
    Serial.print("  Data   : D"); Serial.println(deviceConfig.shiftRegisters.dataPin);
    Serial.print("  Clock  : D"); Serial.println(deviceConfig.shiftRegisters.clockPin);
    Serial.print("  Load   : D"); Serial.println(deviceConfig.shiftRegisters.loadPin);
    Serial.print("  Inverted: "); Serial.println(deviceConfig.shiftRegisters.inverted ? "yes" : "no");
  } else {
    Serial.println("  (disabled)");
  }
}

void updateInputs() {
  // Update axes (read ADC, apply calibration, curves)
  axes.update();

  // Update buttons (read pins, debounce, map)
  buttons.update();
}

#if ENABLE_FFB
// Force-feedback tick. Runs at ~1 kHz off the main loop (a millis() gate).
//
// CONCURRENCY: USB report callbacks mutate engine state from the high-priority
// "usbd" task; this tick reads/steps it from the low-priority "loop" task. The
// ffbLock() mutex serializes them (see ffb_lock.h). We hold the lock ONLY across
// engine().update() — pure math, no blocking/USB calls — so the priority
// inversion is bounded and deadlock is impossible. Reading axis positions and
// writing the motor happen outside the lock (loop-owned state).
void updateFFB() {
  uint32_t now = millis();
  if (now - lastFfbTick < 1) return;   // ~1 kHz cap
  lastFfbTick = now;

  // Safety: if USB is detached/suspended, never leave a motor energized.
  if (!TinyUSBDevice.mounted()) {
    ffbMotor.disableAll();
    return;
  }

  uint8_t n = (MAX_FFB_AXES < MAX_AXES) ? MAX_FFB_AXES : MAX_AXES;
  float pos[MAX_FFB_AXES];
  for (uint8_t i = 0; i < n; i++) {
    // Calibrated axis value is centered; normalize the +/-32767 output to -1..1.
    pos[i] = axes.getAxisValue(i) / 32767.0f;
  }

  float force[MAX_FFB_AXES];
  ffbLock();
  ffbRuntime.engine().update(now, pos, force, n);
  ffbUnlock();

  for (uint8_t i = 0; i < n; i++) {
    ffbMotor.setForce(i, force[i]);
  }
}
#endif

void sendHIDReports() {
  // SAFETY: Don't send HID reports in configuration mode
  // This prevents floating pins from generating random input during initial setup
  if (configurationMode && currentMode == MODE_BLE) {
    return;
  }
  
  // Gather axis values
  int16_t axisValues[MAX_AXES];
  for (int i = 0; i < MAX_AXES; i++) {
    axisValues[i] = axes.getAxisValue(i);
  }
  
  // Gather button states (8 bytes = 64 buttons)
  uint8_t buttonBytes[8];
  buttons.getExtendedButtonStates(buttonBytes, 8);
  
  // Send via appropriate interface
  if (currentMode == MODE_USB) {
    usbHID.sendReport(axisValues, buttonBytes);
  } else if (currentMode == MODE_BLE) {
    bleHID.sendReport(axisValues, buttonBytes);
  }
}

void updateBatteryLevel() {
  float vbat = readVBAT();
  
  // Convert voltage to percentage (rough estimate)
  // LiPo: 4.2V = 100%, 3.7V = 50%, 3.0V = 0%
  uint8_t batteryPercent = 100;
  
  if (vbat >= 4.2) {
    batteryPercent = 100;
  } else if (vbat <= 3.0) {
    batteryPercent = 0;
  } else {
    // Linear approximation
    batteryPercent = (uint8_t)((vbat - 3.0) / (4.2 - 3.0) * 100.0);
  }
  
  Serial.print("Battery: ");
  Serial.print(vbat);
  Serial.print("V (");
  Serial.print(batteryPercent);
  Serial.println("%)");

  // Push to the BLE Battery Service so hosts see the real level.
  if (currentMode == MODE_BLE) {
    bleHID.setBatteryLevel(batteryPercent);
  }
}

float readVBAT() {
  // Connect the on-board battery divider (active LOW on the XIAO nRF52840).
  pinMode(VBAT_ENABLE, OUTPUT);
  digitalWrite(VBAT_ENABLE, LOW);

  // VBAT_MV_PER_LSB assumes the 3.0V reference, which the axis pipeline does
  // not use — set it just for this read, then restore.
  analogReference(AR_INTERNAL_3_0);
  analogReadResolution(12);
  delay(1);  // let the ADC settle after the reference switch

  float raw = analogRead(VBAT_PIN);

  // Restore the axes' ratiometric reference (see axes.cpp); keep 12-bit.
  analogReference(AR_VDD4);
  analogReadResolution(12);

  // Keep VBAT_ENABLE driven LOW. Releasing it (high-Z) lets P0.31 float up
  // toward raw VBAT (up to 4.2 V) through the 1M resistor, above the nRF52840's
  // 3.6 V absolute maximum — Seeed's guidance is to hold P0.14 LOW. The divider
  // then costs ~3 uA continuously, which is negligible.

  // raw(0..4095) -> tap mV -> actual battery mV -> volts
  float vbat = raw * VBAT_MV_PER_LSB * VBAT_DIVIDER_COMP / 1000.0;

  return vbat;
}

void blinkStatus(int times) {
  for (int i = 0; i < times; i++) {
    digitalWrite(STATUS_LED_PIN, LED_ON);
    delay(200);
    digitalWrite(STATUS_LED_PIN, LED_OFF);
    delay(200);
  }
}

void handleBLEConfigMode() {
  bool isConnected = bleHID.isConnected();
  
  // Detect new connection
  if (isConnected && !wasConnected) {
    bleConnectionTime = millis();
    configurationMode = true;
    bleHID.setHIDEnabled(false);
    Serial.println("=======================================");
    Serial.println("BLE CONNECTED - Configuration Mode Active");
    Serial.println("HID reports disabled for 60 seconds");
    Serial.println("");
    Serial.println("** SAFETY MODE: All inputs disabled! **");
    Serial.println("Enable only connected axes/buttons in");
    Serial.println("the configurator to prevent noise.");
    Serial.println("");
    Serial.println("Hold MODE button or send 'C' to stay in config mode");
    Serial.println("Send 'H' to enable HID mode immediately");
    Serial.println("=======================================");
  }
  
  // Detect disconnection
  if (!isConnected && wasConnected) {
    configurationMode = false;
    bleHID.setHIDEnabled(false);
    Serial.println("BLE disconnected");
  }
  
  wasConnected = isConnected;
  
  // Auto-enable HID after timeout if still in config mode
  if (configurationMode && isConnected) {
    // Check if mode button is held (stay in config mode).
    // D9 is also held LOW at boot to select BLE. Only treat LOW as a "hold" once
    // D9 has been released (read HIGH) since boot — otherwise a jumper/latching
    // switch to GND would keep HID disabled forever.
    static bool modePinReleased = false;
    bool modePinLow = digitalRead(MODE_SELECT_PIN) == LOW;
    if (!modePinLow) modePinReleased = true;
    bool modeButtonHeld = modePinLow && modePinReleased;
    
    uint32_t elapsedTime = millis() - bleConnectionTime;
    
    if (modeButtonHeld) {
      // Reset timer while button is held
      bleConnectionTime = millis();
      // Only log once per second to avoid flooding
      static uint32_t lastButtonLog = 0;
      if (millis() - lastButtonLog > 1000) {
        Serial.println("Mode button held - staying in config mode");
        lastButtonLog = millis();
      }
    } else if (elapsedTime >= CONFIG_MODE_TIMEOUT) {
      // Re-init SR hardware before enabling HID — prevents ghost inputs if a
      // BLE config write changed SR pin assignments or chip count during the
      // config window.
      buttons.begin(&deviceConfig);
      configurationMode = false;
      bleHID.setHIDEnabled(true);
      Serial.println("Config mode timeout - HID enabled");
    }
  }
}

void handleSerialCommand() {
  // Read available characters into a buffer
  static String commandBuffer = "";
  
  while (Serial.available()) {
    char c = Serial.read();
    
    // Line-based command (ends with newline)
    if (c == '\n' || c == '\r') {
      if (commandBuffer.length() > 0) {
        processCommand(commandBuffer);
        commandBuffer = "";
      }
      return;
    }
    
    commandBuffer += c;
    
    // Single-char commands (backwards compatibility)
    if (commandBuffer.length() == 1) {
      char cmd = commandBuffer[0];
      
      if (cmd == 'C' || cmd == 'c' || cmd == 'H' || cmd == 'h' || cmd == '?') {
        processCommand(commandBuffer);
        commandBuffer = "";
        return;
      }
    }
  }
}
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

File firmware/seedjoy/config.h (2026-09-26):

/**
 * SeedJoy - Configuration Data Structures
 * 
 * Defines the device configuration structure that is stored in Flash
 * and synchronized with the web configurator.
 */

#ifndef CONFIG_H
#define CONFIG_H

#include <Arduino.h>
#include "ffb_config.h"   // ENABLE_FFB gate (Arduino-free)

// Firmware version
#define FIRMWARE_VERSION_MAJOR 0
#define FIRMWARE_VERSION_MINOR 1
#define FIRMWARE_VERSION_PATCH 0

// Hardware constraints
#define MAX_AXES 4
#define MAX_BUTTONS 16
#define MAX_SHIFT_REGISTER_BUTTONS 128  // Up to 16 shift registers * 8 bits
#define MAX_TOTAL_BUTTONS (MAX_BUTTONS + MAX_SHIFT_REGISTER_BUTTONS)
#define MAX_SHIFT_REGISTERS 16
#define MAX_CURVE_POINTS 5

// Pin definitions for XIAO nRF52840
// Reference: https://wiki.seeedstudio.com/XIAO_BLE/

// Mode select button (moved from D0 to avoid conflict with A0)
#define MODE_SELECT_PIN D9  // P1.14 (MISO) - Hold LOW for BLE, HIGH for USB on boot
#define STATUS_LED_PIN LED_RED    // P0.26 (red LED)
#define CONNECTION_LED_PIN LED_BLUE  // P0.06 (blue LED)
// The XIAO nRF52840's RGB LED is common-anode: LOW = lit. (The Seeed variant's
// LED_STATE_ON is 1, which is wrong for this board, so don't rely on it.)
#define LED_ON  LOW
#define LED_OFF HIGH

// Analog axes (4 axes on dedicated ADC pins)
#define AXIS_0_PIN A0  // D0 = P0.02 (ADC1)
#define AXIS_1_PIN A1  // D1 = P0.03 (ADC2)
#define AXIS_2_PIN A2  // D2 = P0.28 (ADC5)
#define AXIS_3_PIN A3  // D3 = P0.29 (ADC6)

// Default shift register pins (74HC165 parallel-in, serial-out)
#define SR_DATA_PIN  D6   // P1.11 (TX) - Serial data out (Q7)
#define SR_CLOCK_PIN D7   // P1.12 (RX) - Shift clock
#define SR_LOAD_PIN  D8   // P1.13 (SCK) - Parallel load (active LOW)

// Legacy direct button pins (optional - primarily using shift registers)
// Only 3 pins allocated, rest disabled (0xFF)
const uint8_t DEFAULT_BUTTON_PINS[MAX_BUTTONS] = {
  D4,   // P0.04 (SDA/A4)
  D5,   // P0.05 (SCL/A5)
  D10,  // P1.15 (MOSI)
  0xFF, 0xFF, 0xFF, 0xFF, 0xFF,  // Unused
  0xFF, 0xFF, 0xFF, 0xFF, 0xFF,
  0xFF, 0xFF, 0xFF
};

// Operation modes
enum OperationMode {
  MODE_USB = 0,
  MODE_BLE = 1,
  MODE_AUTO = 2  // Future: auto-switch based on USB connection
};

// Axis curve types
enum AxisCurve {
  CURVE_LINEAR = 0,
  CURVE_EXPO = 1,
  CURVE_CUSTOM = 2
};

// Axis configuration
struct AxisConfig {
  uint8_t pin;              // ADC pin number
  bool enabled;             // Is this axis enabled?
  bool inverted;            // Invert axis direction
  uint16_t min;             // Calibrated minimum (0-4095)
  uint16_t center;          // Calibrated center (0-4095)
  uint16_t max;             // Calibrated maximum (0-4095)
  uint8_t deadzone;         // Deadzone percentage (0-50)
  AxisCurve curveType;      // Curve type
  float expoFactor;         // Expo curve factor (0.0-1.0)
  float customCurve[MAX_CURVE_POINTS]; // Custom curve points (0.0-1.0)
  uint8_t smoothing;        // Smoothing samples (0=off, 2,4,8)
  
  // Defaults
  AxisConfig() : 
    pin(0xFF), enabled(false), inverted(false),
    min(0), center(2048), max(4095),
    deadzone(5), curveType(CURVE_LINEAR), 
    expoFactor(0.0f), smoothing(0) {
      for (int i = 0; i < MAX_CURVE_POINTS; i++) {
        customCurve[i] = i / (float)(MAX_CURVE_POINTS - 1);
      }
    }
};

// Button configuration
struct ButtonConfig {
  uint8_t pin;              // GPIO pin number
  bool enabled;             // Is this button enabled?
  uint8_t logicalNumber;    // Logical button number (0-15)
  bool inverted;            // Invert logic (normally HIGH = pressed)
  
  // Defaults
  ButtonConfig() : 
    pin(0xFF), enabled(false), 
    logicalNumber(0), inverted(false) {}
};

// Shift Register configuration (74HC165 / CD4021)
struct ShiftRegisterConfig {
  bool enabled;             // Shift registers enabled
  uint8_t numChips;         // Number of chained shift registers (1-16)
  uint8_t dataPin;          // Data pin (SER_OUT / Q7)
  uint8_t clockPin;         // Clock pin (CLK)
  uint8_t loadPin;          // Latch/Load pin (SH/LD)
  bool inverted;            // true = input LOW means pressed (pull-up + switch to GND)
  
  // Defaults (using predefined SR_ pins)
  // SR-only mode: 7 chips = 56 buttons (covers up to ~50 physical buttons)
  ShiftRegisterConfig() :
    enabled(true), numChips(7),
    dataPin(D6), clockPin(D7), loadPin(D8),
    // Standard wiring is a 10k pull-up per input with the switch to GND, so a
    // pressed button reads LOW -> invert so pressed = 1 in the HID report.
    inverted(true) {}
};
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

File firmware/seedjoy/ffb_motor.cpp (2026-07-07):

/**
 * SeedJoy - Force Feedback motor output (Phase 4)
 */
#include "ffb_config.h"
#if ENABLE_FFB

#include "ffb_motor.h"
#include "config.h"
#include <Arduino.h>
#include <math.h>

// PWM duty is 8-bit on the Adafruit nRF52 core by default (analogWrite 0..255).
static const int PWM_MAX = 255;

MotorOutput::MotorOutput() : begun_(false) {
  for (int a = 0; a < MAX_FFB_AXES; a++) {
    axis_[a].type = MOTOR_DRIVER_NONE;
    axis_[a].pinA = 0xFF;
    axis_[a].pinB = 0xFF;
    axis_[a].invert = false;
  }
}

void MotorOutput::begin() {
  // ---- Phase 4: assign real driver(s) here. Example (option A, 1 axis) ----
  //   axis_[0].type   = MOTOR_DRIVER_DUAL_PWM;  // DRV8871
  //   axis_[0].pinA   = D4;                      // IN1
  //   axis_[0].pinB   = D5;                      // IN2
  //   axis_[0].invert = false;                   // flip if the spring pushes away
  // Left as NONE on purpose so nothing drives an unknown pin.

  for (int a = 0; a < MAX_FFB_AXES; a++) {
    if (axis_[a].type == MOTOR_DRIVER_NONE) continue;
    if (axis_[a].pinA != 0xFF) { pinMode(axis_[a].pinA, OUTPUT); analogWrite(axis_[a].pinA, 0); }
    if (axis_[a].pinB != 0xFF) {
      pinMode(axis_[a].pinB, OUTPUT);
      if (axis_[a].type == MOTOR_DRIVER_DUAL_PWM) analogWrite(axis_[a].pinB, 0);
      else                                        digitalWrite(axis_[a].pinB, LOW);
    }
  }

  pinMode(STATUS_LED_PIN, OUTPUT);
  driveLedViz(0.0f);
  begun_ = true;
}

bool MotorOutput::hasMotorPins() const {
  for (int a = 0; a < MAX_FFB_AXES; a++) {
    if (axis_[a].type != MOTOR_DRIVER_NONE) return true;
  }
  return false;
}

void MotorOutput::setForce(uint8_t axis, float f) {
  if (!begun_ || axis >= MAX_FFB_AXES) return;
  if (f > 1.0f) f = 1.0f;
  if (f < -1.0f) f = -1.0f;
  if (axis_[axis].invert) f = -f;

  driveAxis(axis, f);

  if (axis == 0) driveLedViz(f);
}

void MotorOutput::driveAxis(uint8_t axis, float f) {
  const MotorAxisConfig& c = axis_[axis];
  if (c.type == MOTOR_DRIVER_NONE) return;

  uint8_t duty = (uint8_t)(fabsf(f) * PWM_MAX + 0.5f);
  bool forward = (f >= 0.0f);

  switch (c.type) {
    case MOTOR_DRIVER_PWM_DIR:
      if (c.pinB != 0xFF) digitalWrite(c.pinB, forward ? HIGH : LOW);
      if (c.pinA != 0xFF) analogWrite(c.pinA, duty);
      break;
    case MOTOR_DRIVER_DUAL_PWM:
      // DRV8871-style: drive one input with PWM, hold the other at 0.
      if (forward) {
        if (c.pinA != 0xFF) analogWrite(c.pinA, duty);
        if (c.pinB != 0xFF) analogWrite(c.pinB, 0);
      } else {
        if (c.pinA != 0xFF) analogWrite(c.pinA, 0);
        if (c.pinB != 0xFF) analogWrite(c.pinB, duty);
      }
      break;
    default:
      break;
  }
}

void MotorOutput::disableAll() {
  for (int a = 0; a < MAX_FFB_AXES; a++) {
    if (axis_[a].type == MOTOR_DRIVER_NONE) continue;
    if (axis_[a].pinA != 0xFF) analogWrite(axis_[a].pinA, 0);
    if (axis_[a].pinB != 0xFF) {
      if (axis_[a].type == MOTOR_DRIVER_DUAL_PWM) analogWrite(axis_[a].pinB, 0);
      else                                        digitalWrite(axis_[a].pinB, LOW);
    }
  }
  if (begun_) driveLedViz(0.0f);
}

// XIAO status LED is active-LOW: analogWrite(255) = off, analogWrite(0) = full.
void MotorOutput::driveLedViz(float f0) {
  uint8_t mag = (uint8_t)(fabsf(f0) * PWM_MAX + 0.5f);
  analogWrite(STATUS_LED_PIN, PWM_MAX - mag);
}

#endif // ENABLE_FFB

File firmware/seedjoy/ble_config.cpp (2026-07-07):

/**
 * SeedJoy - BLE Configuration Service Implementation
 */

#include "ble_config.h"
#include <Arduino.h>

// Static instance pointer for callbacks
BLEConfigService* BLEConfigService::instance_ = nullptr;

BLEConfigService::BLEConfigService() 
  : service_(BLE_CONFIG_SERVICE_UUID),
    configReadChar_(BLE_CONFIG_READ_UUID),
    configWriteChar_(BLE_CONFIG_WRITE_UUID),
    statusChar_(BLE_STATUS_UUID),
    axesMonitorChar_(BLE_AXES_MONITOR_UUID),
    buttonsMonitorChar_(BLE_BUTTONS_MONITOR_UUID),
    calibrateChar_(BLE_CALIBRATE_UUID),
    config_(nullptr),
    storage_(nullptr),
    axes_(nullptr),
    buttons_(nullptr),
    configBufferSize_(0),
    receiveBufferLen_(0),
    receiveBraceDepth_(0) {
  
  instance_ = this;
  memset(&axisData_, 0, sizeof(axisData_));
  memset(&buttonsData_, 0, sizeof(buttonsData_));
}

bool BLEConfigService::begin(DeviceConfig* config, StorageManager* storage, AxesProcessor* axes) {
  config_ = config;
  storage_ = storage;
  axes_ = axes;
  
  Serial.println("Configuring BLE Config Service characteristics...");
  
  // Configure ALL characteristics BEFORE starting the service
  // (Bluefruit requires characteristics to be added before service.begin())
  
  // Configure Config Read characteristic (Read only, notify)
  configReadChar_.setProperties(CHR_PROPS_READ | CHR_PROPS_NOTIFY);
  configReadChar_.setPermission(SECMODE_OPEN, SECMODE_NO_ACCESS);
  configReadChar_.setMaxLen(MAX_CONFIG_SIZE);
  configReadChar_.setFixedLen(false);
  uint16_t err1 = configReadChar_.begin();
  Serial.print("Config Read Char initialized: ");
  Serial.println(err1 == ERROR_NONE ? "SUCCESS" : "FAILED");
  
  // Configure Config Write characteristic (Write only)
  configWriteChar_.setProperties(CHR_PROPS_WRITE | CHR_PROPS_WRITE_WO_RESP);
  configWriteChar_.setPermission(SECMODE_NO_ACCESS, SECMODE_OPEN);
  configWriteChar_.setMaxLen(MAX_CONFIG_SIZE);
  configWriteChar_.setFixedLen(false);
  configWriteChar_.setWriteCallback(configWriteCallback);
  uint16_t err2 = configWriteChar_.begin();
  Serial.print("Config Write Char initialized: ");
  Serial.println(err2 == ERROR_NONE ? "SUCCESS" : "FAILED");
  
  // Configure Status characteristic (Read, notify)
  statusChar_.setProperties(CHR_PROPS_READ | CHR_PROPS_NOTIFY);
  statusChar_.setPermission(SECMODE_OPEN, SECMODE_NO_ACCESS);
  statusChar_.setMaxLen(256);
  statusChar_.setFixedLen(false);
  statusChar_.begin();
  
  // Configure Axes Monitor characteristic (Read, notify)
  axesMonitorChar_.setProperties(CHR_PROPS_READ | CHR_PROPS_NOTIFY);
  axesMonitorChar_.setPermission(SECMODE_OPEN, SECMODE_NO_ACCESS);
  axesMonitorChar_.setMaxLen(sizeof(AxisMonitorData));
  axesMonitorChar_.setFixedLen(true);
  axesMonitorChar_.begin();
  
  // Configure Buttons Monitor characteristic (Read, notify)
  buttonsMonitorChar_.setProperties(CHR_PROPS_READ | CHR_PROPS_NOTIFY);
  buttonsMonitorChar_.setPermission(SECMODE_OPEN, SECMODE_NO_ACCESS);
  buttonsMonitorChar_.setMaxLen(sizeof(ButtonsMonitorData));
  buttonsMonitorChar_.setFixedLen(true);
  buttonsMonitorChar_.begin();
  
  // Configure Calibrate characteristic (Write)
  calibrateChar_.setProperties(CHR_PROPS_WRITE | CHR_PROPS_WRITE_WO_RESP);
  calibrateChar_.setPermission(SECMODE_NO_ACCESS, SECMODE_OPEN);
  calibrateChar_.setMaxLen(16);
  calibrateChar_.setFixedLen(false);
  calibrateChar_.setWriteCallback(calibrateCallback);
  calibrateChar_.begin();
  
  // NOW start the service (adds all characteristics to the service)
  service_.begin();
  Serial.print("BLE Config Service started with UUID: ");
  Serial.println(BLE_CONFIG_SERVICE_UUID);
  
  // Serialize initial config
  serializeConfig();
  
  // Send initial status
  sendStatus("SeedJoy Config Service Ready", true);
  
  Serial.println("BLE Config Service initialized");
  
  return true;
}
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

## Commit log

2026-02-16 feat: real-time button monitoring (firmware + configurator UI)
2026-02-17 fix: prevent floating pin chaos - disable all inputs by default
    BREAKING CHANGE: All axes and buttons are now disabled by default for safety.
    Users must explicitly enable inputs in the configurator after connecting hardware.
    Changes:
    - Disable all axes/buttons in default config (config.h)
    - Extend BLE config timeout from 10s to 60s
    - Add safety gate in sendHIDReports() to block output during config mode
    - Update README with safety warnings and new workflow
    - Add troubleshooting section for random input issues
    Fixes the critical bug where floating pins generated random HID input,
    causing keyboard/mouse chaos and system shutdowns on macOS/Windows.
    [config.h, seedjoy.ino]
2026-02-17 feat: add enable/disable controls to configurator UI
    - Add checkbox to enable/disable each axis and button
    - Add 'Enable All' / 'Disable All' bulk buttons for axes and buttons
    - Pin selectors are disabled when input is unchecked
    - Add safety notice warning about floating pins
    - Update default config to match firmware (all disabled by default)
    - Add CSS styling for new UI elements
    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
2026-02-17 fix: initialize BLE config service before advertising
    The config service was being initialized AFTER BLE advertising started,
    which meant the service UUID wasn't included in the advertising packet.
    This caused the configurator to fail to discover the config service
    characteristics (read/write/monitor).
    - Remove auto-start of advertising from bleHID.begin()
    - Manually start advertising in seedjoy.ino AFTER bleConfig.begin()
    - Ensures all GATT services are registered before advertising
    This fixes the 'configuration service not available' error in the
    web configurator when attempting to read/write device config.
    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
    [ble_hid.cpp, seedjoy.ino]
2026-02-17 fix: disable BLE bonding and add debug logging for config service
    - Disable BLE security/bonding (setIOCaps false, clearBonds)
    - Prevents OS pairing cache issues requiring device forget/re-pair
    - Add Serial debug output for config service UUID
    - HID devices don't need pairing security
    [ble_config.cpp, ble_hid.cpp]
2026-02-17 fix: remove clearBonds() call - method doesn't exist in Bluefruit library
    setIOCaps(false, false, false) is sufficient to disable bonding
    [ble_hid.cpp]
2026-02-17 fix: add config service UUID to BLE advertising packet
    - Include config service UUID in advertising packet
    - WebBluetooth requires services in optionalServices to be advertised
    - Without this, getPrimaryService() fails with service not found
    - Fixes 'Configuration service not available' error
    [ble_hid.cpp]
2026-02-17 fix: properly add config service to BLE advertising using addService()
    - Changed startAdvertising() to accept BLEService* parameter
    - Use addService() with config service reference instead of addUuid() with string
    - String literals don't work with addUuid() - causes silent failure
    - Pass &bleConfig.getService() from main sketch
    - This ensures config service UUID is properly advertised for WebBluetooth discovery
    - Fixes root cause of 'Configuration service not available' error
    [ble_hid.cpp, seedjoy.ino]
2026-02-17 debug: add detailed logging for BLE service discovery
    - Add console logging in configurator to track service/characteristic discovery
    - Add Serial logging in firmware for service initialization and advertising
    - Log whether config service is added to scan response
    - This will help identify exactly where discovery fails
    [ble_config.cpp, ble_hid.cpp]
2026-02-17 fix: remove service.started() call - method doesn't exist
    [ble_config.cpp]
2026-02-17 fix: move config service to main advertising packet
    - WebBluetooth may not discover services only in scan response
    - Move config service from scan response to main advertising packet
    - Move device name to scan response only to save space
    - Both HID and config services now in main advertising for reliable discovery
    [ble_hid.cpp]
2026-02-17 debug: add characteristic initialization logging and fix button parsing
    - Add debug output for characteristic initialization success/failure
    - Fix DataView buffer offset bug in button data parsing
    - Restore service.begin() before characteristic.begin() order
    - Will help identify why characteristics aren't discovered
    [ble_config.cpp]
2026-02-17 fix: remove extra closing brace causing compilation error
    [ble_config.cpp]
2026-02-17 fix: add size validation to button parsing and better error logging
    - Add byteLength check before parsing button data to prevent RangeError
    - Add try/catch with error messages for characteristic discovery
    - Will show exact error why Read/Write characteristics aren't found
2026-02-17 fix: rate limit mode button logs and add clearer BLE init markers
    - Only log mode button held once per second instead of every loop
    - Add prominent section markers for BLE initialization
    - Makes it easier to see characteristic initialization results
    - Prevents serial monitor flooding
    [seedjoy.ino]
2026-02-17 fix: use dataView directly instead of buffer in axis parsing
    - Same buffer offset bug as button parsing
    - Use dataView parameter directly to preserve byteOffset
    - Add size validation to axis data parsing
    - Prevents RangeError in axis data handler
2026-02-17 fix: initialize characteristics BEFORE service.begin()
    CRITICAL FIX: Bluefruit requires characteristics to be configured and begun
    BEFORE calling service.begin(), otherwise they don't get added to the service.
    This is why WebBluetooth couldn't find any characteristics - they weren't
    in the service! The service existed but was empty.
    Correct order:
    1. characteristic.begin() for all characteristics
    2. service.begin() to register the service with its characteristics
    This should finally make Read/Write characteristics discoverable.
    [ble_config.cpp]
2026-02-17 feat: add WebSerial support with dual-mode connection toggle
    - Created serial.js for WebSerial communication (USB alternative to BLE)
    - Added connection mode toggle UI (Bluetooth/USB Serial buttons)
    - Updated app.js to support both BLE and Serial connections
    - Added CSS styling for mode selector
    - Enhanced firmware serial command handler for line-based commands
    - Added serial commands: read_config, write_config:{JSON}, ping
    - Users can now switch between BLE and USB Serial connections
    - Solves BLE discovery issues by providing reliable USB fallback
    Benefits:
    - No more BLE characteristic discovery problems
    - Easier debugging via serial console
    - More reliable config read/write over USB
    - Sam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
    [app.js, seedjoy.ino]
2026-02-17 fix: correct pin configuration for XIAO nRF52840
    Critical fixes based on official Seeed Studio pinmap:
    - Move MODE_SELECT_PIN from D0 to D9 (D0 conflicts with A0)
    - Define shift register pins: D6 (data), D7 (clock), D8 (load)
    - Minimize default button pins to D4, D5, D10 (rest disabled)
    - Update ShiftRegisterConfig defaults to use D6/D7/D8
    - Add detailed pin comments with chip pin numbers
    This fixes the conflict where MODE_SELECT_PIN and AXIS_0 were
    both using the same pin (P0.02), and prepares the firmware for
    the primary use case: 4 analog axes + shift register buttons.
    Pin allocation:
    - A0-A3 (P0.02/03/28/29): 4 analog axes
    - D6-D8 (P1.11/12/13): Shift register interface
    - D9 (P1.14): M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
    [config.h, seedjoy.ino]
2026-02-17 fix: update configurator UI with correct XIAO nRF52840 pin mappings
    Updates to match firmware pin configuration changes:
    Configurator UI (config.js):
    - Update default button pins to D4, D5, D10 (rest disabled as 0xFF)
    - Set shift register defaults to D6 (0x2B), D7 (0x2C), D8 (0x2D)
    - Fix getAvailablePins() with correct XIAO pin mappings:
    * D0-D3 as A0-A3 (analog axes)
    * D4-D10 with correct chip pins (P0.04, P0.05, P1.11-P1.15)
    * Remove incorrect pin mappings
    - Add reference to official Seeed documentation
    HTML Updates (index.html):
    - Add hardware pin reference diagram in pinout section
    - Show axes, shift register, and other pin assignments
    - Update shift register hint with default pi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
    [config.js]
2026-07-07 fix: resolve audit blockers and high-priority issues
    Fixes from docs/audit.md (tree now compiles clean, exit 0):
    - B1: correct float JSON key pattern in ble_config.cpp (was a stray
    backslash → compile error; also matched quoted values, never numbers)
    - B2: BLE HID now presents the joystick descriptor. Switched from
    BLEHidAdafruit to BLEHidGeneric(1,0,0), added Report ID 1 to the map,
    moved setReportMap/setReportLen/setHidInfo before begin(), and updated
    both inputReport() sites to ID 1. Previously enumerated as keyboard+mouse.
    - B3: remove config file before write (Adafruit LittleFS FILE_O_WRITE is
    append-mode; repeated saves grew the file and reverted to defaults on boot)
    - H1: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
    [ble_config.cpp, ble_hid.cpp, buttons.cpp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]
2026-07-07 feat: force-feedback (USB PID) implementation, gated behind ENABLE_FFB
    Implements Phases 1-3 of docs/ffb-plan.md plus a Phase 4 scaffold. The whole
    stack is gated behind ENABLE_FFB (default 0); with the gate off the compiled
    flash image is byte-identical to the prior baseline (verified by diffing the
    .hex against commit 8cd31f9), so the shippable input device is untouched.
    Verified without hardware (firmware/tests, 41 assertions, run_tests.sh):
    - Effect engine (ffb_engine): constant/ramp/spring/damper/inertia/friction/
    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
2026-07-07 docs: flag FFB force-loop data race (usbd task vs loop)
    Verified on this core that USB report callbacks run in the high-priority
    FreeRTOS "usbd" task (tud_task loop) while updateFFB() reads engine state from
    the low-priority "loop" task — a live data race in the ON path, not a
    future-ISR concern as previously implied. Corrects the code comments and the
    ffb-plan.md status to list this alongside the unvalidated descriptor, with the
    fix (single-writer report queue) as the first next step. No functional change;
    FFB remains gated off by default.
    [seedjoy.ino]
2026-07-07 feat(ffb): production-grade hardening + physical test plan
    Takes the gated FFB path from "compiles" to production-grade code. FFB remains
    gated behind ENABLE_FFB (default 0); re-verified the flash image is still
    byte-identical to baseline 8cd31f9 with the gate off.
    Concurrency (the load-bearing fix):
    - ffb_lock: a priority-inheriting FreeRTOS mutex serializes all engine access
    between the high-priority usbd task (USB report callbacks) and the low-priority
    loop task (force tick). Chosen over a report queue because Create New Effect ->
    Block Load is a synchronous control transfer that must be serviced in the usbd
    task. The loop holds the lock only across the pure-math engine step, so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
    [ffb_motor.cpp]
2026-07-07 docs(ffb): note axis-enable prerequisite in physical test plan
    Axes ship disabled (audit safety default) and AxesProcessor::update() reports
    position 0 for a disabled axis, so spring/damper effects produce zero force
    until axis 0 is enabled + calibrated in the configurator. Constant/sine/ramp
    are position-independent and work regardless, which makes an unconfigured
    spring look broken. Added the prerequisite to the test plan (§0 and §5) plus a
    note that force output needs PID "enable actuators" (automatic under Linux
    hid-pidff; manual only for raw-script testers).
2026-09-26 fix: make SeedJoy work on real Seeed XIAO nRF52840 hardware
    Firmware
    - USB: force re-enumeration after adding the HID interface. The nRF52
    core enumerates CDC-only before setup(), so the joystick never appeared.
    - LEDs: XIAO RGB LED is active-LOW (variant's LED_STATE_ON is wrong);
    add LED_ON/LED_OFF and stop Bluefruit's auto connection LED.
    - D9: only treat LOW as "hold config mode" after it has been released
    since boot, so a BLE jumper/latching switch no longer blocks HID forever.
    - Shift registers: default inverted=true (pull-up + switch to GND means
    LOW = pressed); previously every idle button read as pressed.
    - Storage: repair invalid pin numbers left by older configurator builds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
    [app.js, ble_hid.cpp, config.h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]
2026-09-26 feat(pcb): SeedJoy test board rev A (KiCad 10)
    Through-hole 130x75 mm 2-layer board that exercises the firmware:
    - XIAO nRF52840 on 1x7 sockets
    - 74HC165 (socketed) + 8 buttons with 10k bussed SIP pull-ups
    - J7 chain-input header (3V3/GND/CLK/LOAD/SER) with R1 pull-up, so a
    user's own 74HC165 board can be daisy-chained in front of it
    - 4-way DIP switch on D4/D5/D10 (GPIO buttons) and D9 (USB/BLE mode)
    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
    [seedjoy_testboard.kicad_pcb, seedjoy_testboard.kicad_sch]
2026-09-26 fix: audit firmware, configurator and test board against real hardware
    - Axes use a ratiometric ADC reference (AR_VDD4): 0..4095 == 0..VDD, so a
    3.3 V pot centres at ~2048. AR_DEFAULT (3.6 V internal) capped the stick
    at ~3750 with centre ~1877, outside the default calibration.
    - Hold VBAT_ENABLE (P0.14) LOW from boot and never release it; a floating
    P0.14 lets P0.31 rise toward raw VBAT, above the nRF52840 3.6 V abs max.
    - New serial commands stream_axes / stop_axes (20 Hz raw + processed).
    Configurator
    - Calibration over USB Serial was showing SIMULATED axis movement: the
    firmware never sent axis data over serial, serial.js lacked isConnected(),
    and onAxisData was only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
    [seedjoy_testboard.kicad_pcb]
2026-09-26 docs: paper-fit pre-order check, 32-button tester limit, realistic stick range
2026-09-27 docs(pcb): India order plan (Sharvi Electronics single order + backups)
2026-09-27 docs(pcb): tactile switches must be 4-pin; source from Robocraze
